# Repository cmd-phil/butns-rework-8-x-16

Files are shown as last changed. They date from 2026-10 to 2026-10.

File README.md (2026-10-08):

# Overview

128 button grid as a rework of jhbruhns 64 clone heavily based on previous work by [hugelton/btns](https://github.com/hugelton/Btns).

overview image

Uses a Rasperry Pi Pico Microcontroller, NeoPixel RGB LEDs (SK6812), cheap buttons and a 3d-printed case and button-overlay.

# Building

It is highly recommended to order the PCB assembled from JLCPCB. That assembly will include everything other than the parts in the BOM.

## BOM

| Part | Quantity | Source | Required | 
|---|---|---|---|
| PCB with components | 1 | JLCPCB, ordered with Gerber and Assembly files from latest release. Gerber: `butns-JLCPCB.zip`, BOM: `butns_bom_jlc.csv`, CPL: `butns_cpl_jlc.csv`. | yes | 
| Raspberry Pi Pico | 1 | Original Raspberry Pi Pico, or [USB-C Variant](https://de.aliexpress.com/item/1005007393927221.html) | yes | |
| M2.5x6 Button Head Screws | 5 | [M2.5x6](https://www.aliexpress.com/item/32810852732.html) | yes | 
| Case | 1 | 3d-printed (FDM). `case.stl` contains the top and bottom half. In the image, it is printed in black PLA, 0.2mm layerheight. | yes | 
| Button Matrix | 1 | 3d-printed (FDM). Print `buttons.stl` with white PLA and 0.12mm layerheight and no infill, 2 wall lines, concentric top infill. These should guide the LEDs light well. Optional: Add `buttons-black-blockers.stl` while importing as a multi-material print and print those in black to block light from neighboring buttons | yes (black blockers optional) | 
| Button TPU Case Inlay | 1 | 3d-printed (FDM). Print with TPU, perhaps in black. Will help against rattling of the buttons in the case. | no | 
| SMD 2.54" Pin Header 1x8 Type A | 1 | [1x8 Type A](https://www.aliexpress.com/item/1005005203849802.html) | no, for tilt | 
| MPU6050 module | 1 | [MPU6050 Module](https://www.aliexpress.com/item/1005006396343851.html) | no, for tilt | 

## Assembly

Flash microcontroller with `firmware.uf2`. Solder MCU and Pin-Header to PCB. Screw everything into the case. Done!

Hint: The cases Top half has one specific orientation where it fits nicely: The top-screw-posts of the top-half with the larger cutoaways go to the side opposite of the USB Connector.

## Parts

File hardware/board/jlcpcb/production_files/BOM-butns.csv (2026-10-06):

Comment | Designator | Footprint | LCSC | Quantity
100nF | C1,C10,C100,C101,C102,C103,C104,C105,C106,C107,C108,C109,C11,C110,C111,C112,C113,C114,C115,C116,C117,C118,C119,C12,C120,C121,C122,C123,C124,C125,C126,C127,C128,C129,C13,C14,C15,C16,C17,C18,C19,C2,C20,C21,C22,C23,C24,C25,C26,C27,C28,C29,C3,C30,C31,C32,C33,C34,C35,C36,C37,C38,C39,C4,C40,C41,C42,C43,C44,C45,C46,C47,C48,C49,C5,C50,C51,C52,C53,C54,C55,C56,C57,C58,C59,C6,C60,C61,C62,C63,C64,C65,C66,C67,C68,C69,C7,C70,C71,C72,C73,C74,C75,C76,C77,C78,C79,C8,C80,C81,C82,C83,C84,C85,C86,C87,C88,C89,C9,C90,C91,C92,C93,C94,C95,C96,C97,C98,C99 | C_0603_1608Metric | C14663 | 129
1N4148WS | D10,D11,D12,D129,D13,D130,D131,D132,D133,D134,D135,D136,D137,D138,D139,D14,D140,D141,D142,D143,D144,D145,D146,D147,D148,D149,D15,D150,D151,D152,D153,D154,D155,D156,D157,D158,D159,D16,D160,D161,D162,D163,D164,D165,D166,D167,D168,D169,D17,D170,D171,D172,D173,D174,D175,D176,D177,D178,D179,D18,D180,D181,D182,D183,D184,D185,D186,D187,D188,D189,D19,D190,D191,D192,D2,D20,D21,D22,D23,D24,D25,D26,D27,D28,D29,D3,D30,D31,D32,D33,D34,D35,D36,D37,D38,D39,D4,D40,D41,D42,D43,D44,D45,D46,D47,D48,D49,D5,D50,D51,D52,D53,D54,D55,D56,D57,D58,D59,D6,D60,D61,D62,D63,D64,D65,D7,D8,D9 | D_SOD-323 | C2128 | 128
SK6812-EC20 | D1,D100,D101,D102,D103,D104,D105,D106,D107,D108,D109,D110,D111,D112,D113,D114,D115,D116,D117,D118,D119,D120,D121,D122,D123,D124,D125,D126,D127,D128,D193,D194,D195,D196,D197,D198,D199,D200,D201,D202,D203,D204,D205,D206,D207,D208,D209,D210,D211,D212,D213,D214,D215,D216,D217,D218,D219,D220,D221,D222,D223,D224,D225,D226,D227,D228,D229,D230,D231,D232,D233,D234,D235,D236,D237,D238,D239,D240,D241,D242,D243,D244,D245,D246,D247,D248,D249,D250,D251,D252,D253,D254,D255,D256,D66,D67,D68,D69,D70,D71,D72,D73,D74,D75,D76,D77,D78,D79,D80,D81,D82,D83,D84,D85,D86,D87,D88,D89,D90,D91,D92,D93,D94,D95,D96,D97,D98,D99 | SK6812-EC20 | C2909058 | 128
SW_Push | SW1,SW10,SW100,SW101,SW102,SW103,SW104,SW105,SW106,SW107,SW108,SW109,SW11,SW110,SW111,SW112,SW113,SW114,SW115,SW116,SW117,SW118,SW119,SW12,SW120,SW121,SW122,SW123,SW124,SW125,SW126,SW127,SW128,SW13,SW14,SW15,SW16,SW17,SW18,SW19,SW2,SW20,SW21,SW22,SW23,SW24,SW25,SW26,SW27,SW28,SW29,SW3,SW30,SW31,SW32,SW33,SW34,SW35,SW36,SW37,SW38,SW39,SW4,SW40,SW41,SW42,SW43,SW44,SW45,SW46,SW47,SW48,SW49,SW5,SW50,SW51,SW52,SW53,SW54,SW55,SW56,SW57,SW58,SW59,SW6,SW60,SW61,SW62,SW63,SW64,SW65,SW66,SW67,SW68,SW69,SW7,SW70,SW71,SW72,SW73,SW74,SW75,SW76,SW77,SW78,SW79,SW8,SW80,SW81,SW82,SW83,SW84,SW85,SW86,SW87,SW88,SW89,SW9,SW90,SW91,SW92,SW93,SW94,SW95,SW96,SW97,SW98,SW99 | SW_Push_1P1T_XKB_TS-1187A | C318884 | 128
74LVC1G17 | U2 | SOT-23-5_HandSoldering | C7836 | 1
Pico | U1 | RPi_Pico_SMD_TH |  | 1

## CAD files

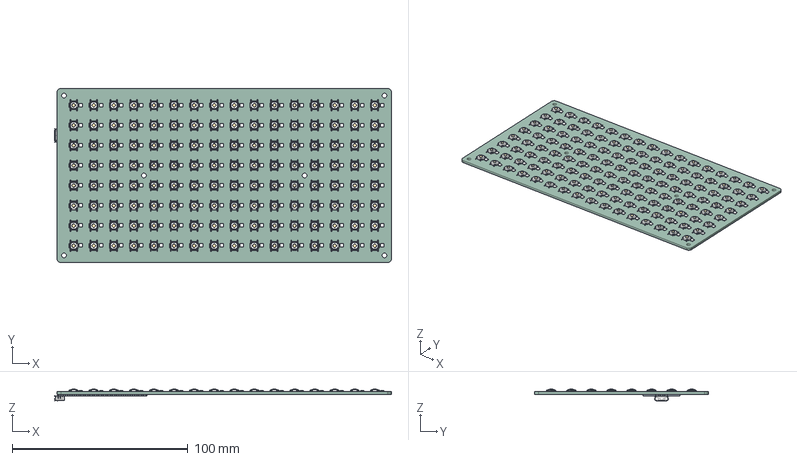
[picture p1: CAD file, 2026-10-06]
hardware/board/butns.step
191.8 x 99.0 x 6.82 mm
SK6812-EC20 x 128
TS-1187A v2 x 128
Raspberry Pi Pico v6
butns_PCB

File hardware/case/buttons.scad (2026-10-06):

include <./roundedcube.scad>

height = 5.3;

s = 8.5;

px = 11.43;
py = 11.4;

cols = 16;
rows = 8;

inlayslack = 1;
rubberslack = .6;

inlayheight = 2.6 - inlayslack;

w = 0.42*3;
h = 0.12*3;

cross = true;

only_blockers = false;

only_inlay = false;

if(!only_blockers && !only_inlay) {
intersection() {
difference() {
union() {
for(x=[0:cols-1]) for(y=[0:rows-1])
translate([x * px, y * py, height / 2]) roundedcube([s, s, height], center = true, radius = 1.5, apply_to = "zmax");

//translate([- s, -s, 0])cube([7 * px + s * 2, 7 * py + s * 2, inlayheight ]);
if (cross) {
for(k=[1-cols/2:rows-1+cols/2])
translate([cols/2 * px, k * py, h/2]) rotate([0, 0, 45]) cube([2*(cols+rows)*px, w, h], center = true);

for(k=[-cols/2:rows-2+cols/2])
translate([cols/2 * px, k * py, h/2]) rotate([0, 0, -45]) cube([2*(cols+rows)*px, w, h], center = true);
} else {
for(x=[0:cols-1]) for(y=[0:rows-1]) {
translate([x * px, y * py - s / 4, h/2]) cube([12, w, h], center=true);
translate([x * px, y * py + s / 4, h/2]) cube([12, w, h], center=true);
translate([x * px - s / 4, y * py, h/2]) cube([w, 12, h], center=true);
translate([x * px + s / 4, y * py, h/2]) cube([w, 12, h], center=true);
}
}

}
translate([3.5 * px, 3.5 * py, 0]) cylinder(h = 20, d = 5.4, center = true);
translate([(cols - 4.5) * px, 3.5 * py, 0]) cylinder(h = 20, d = 5.4, center = true);
translate([-px/2-1, -py/2-1, 0]) cylinder(h = 20, d = 5.8, center = true);
translate([(cols - 0.5) * px+1, (rows - 0.5) * py+1, 0]) cylinder(h = 20, d = 5.8, center = true);
translate([-px/2-1, (rows - 0.5) * py+1, 0]) cylinder(h = 20, d = 5.8, center = true);
translate([(cols - 0.5) * px+1, -py/2-1, 0]) cylinder(h = 20, d = 5.8, center = true);

}
translate([-s/2-1.5, -s/2-1.5, -1]) roundedcube([cols*px-2.9+3, rows*py-2.9+3, 10], radius=1.5, center=false, apply_to = "zmax");


}

for(x=[0:cols-1]) for(y=[0:rows-1])
translate([x * px + s/2, y * py, inlayheight / 2]) cube([3.25, s/3, inlayheight], center = true);

for(y=[0:rows-1])
translate([-1 * px + s - 1, y * py, inlayheight / 2]) cube([2.75, s/4, inlayheight], center = true);
}
if (only_blockers && !only_inlay) {
color("blue")
for(x=[0:cols-1]) for(y=[0:rows-1])
translate([x * px - s/2+.15, y * py, (height - 2) / 2]) cube([.4, s-3, height - 2], center = true);
}

if (!only_blockers && only_inlay) {


color("blue") translate([0, 0, inlayheight]) difference() {
 translate([(cols-1)/2*px, (rows-1)/2*py, (inlayslack - rubberslack) / 2]) cube([(cols-1)*px, (rows-1)*py, inlayslack - rubberslack], center = true);
 
 for(x=[0:cols-1]) for(y=[0:rows-1])
translate([x * px, y * py, height / 2]) roundedcube([s+rubberslack, s + rubberslack, height], center = true, radius = 1.5, apply_to = "zmax");

}
}

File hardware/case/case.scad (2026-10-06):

//-----------------------------------------------------------------------
// Yet Another Parameterized Projectbox generator
//
//  This is a box for <template>
//
//  Version 3.3.0 (2024-11-27)
//
// This design is parameterized based on the size of a PCB.
//
// For many/complex cutoutGrills, you might need to adjust
//  the max number of elements in OpenSCAD:
//
//      Preferences->Advanced->Turn off rendering at 250000 elements
//                                                   ^^^^^^
//
//-----------------------------------------------------------------------



include <./YAPP_Box/YAPPgenerator_v3.scad>

//---------------------------------------------------------
// This design is parameterized based on the size of a PCB.
//---------------------------------------------------------
// Note: length/lengte refers to X axis, 
//       width/breedte refers to Y axis,
//       height/hoogte refers to Z axis

/*
      padding-back|<------pcb length --->|<padding-front
                            RIGHT
        0    X-axis ---> 
        +----------------------------------------+   ---
        |                                        |    ^
        |                                        |   padding-right 
      Y |                                        |    v
      | |    -5,y +----------------------+       |   ---              
 B    a |         | 0,y              x,y |       |     ^              F
 A    x |         |                      |       |     |              R
 C    i |         |                      |       |     | pcb width    O
 K    s |         |                      |       |     |              N
        |         | 0,0              x,0 |       |     v              T
      ^ |    -5,0 +----------------------+       |   ---
      | |                                        |    padding-left
      0 +----------------------------------------+   ---
        0    X-as --->
                          LEFT
*/


//-- which part(s) do you want to print?
printBaseShell        = true;
printLidShell         = true;
printSwitchExtenders  = true;
printDisplayClips     = true;

// ********************************************************************
// The Following will be used as the first element in the pbc array

//Defined here so you can define the "Main" PCB using these if wanted
pcbLength           = 99; // front to back (X axis)
// 16 columns: 99 mm + 8 * 11.43 mm
pcbWidth            = 99 + 8 * 11.43; // side to side (Y axis)
pcbThickness        = 1.6; 
standoffHeight      = 15; //-- How much the PCB needs to be raised from the base to leave room for solderings and whatnot
standoffDiameter    = 6;
standoffPinDiameter = 2.5;
standoffHoleSlack   = 0.4;

myPcb = "../butns.stl";

if ($preview)
{
  translate([pcbLength/2+2.5,pcbWidth/2+2.5,pcbThickness + standoffHeight]) 
  {
    rotate([0,0,90]) color("darkgray") import(myPcb);
  }
}
//===================================================================
// *** PCBs ***
// Printed Circuit Boards
//-------------------------------------------------------------------
//  Default origin =  yappCoordPCB : yappCoordBoxInside[0,0,0]
//
//  Parameters:
//   Required:
//    p(0) = name
//    p(1) = length
//    p(2) = width
//    p(3) = posx
//    p(4) = posy
//    p(5) = Thickness
//    p(6) = standoff_Height
//    p(7) = standoff_Diameter
//    p(8) = standoff_PinDiameter
//   Optional:
//    p(9) = standoff_HoleSlack (default to 0.4)

//The following can be used to get PCB values elsewhere in the script - not in pcb definition. 
//If "PCB Name" is omitted then "Main" is used
//  pcbLength           --> pcbLength("PCB Name")
//  pcbWidth            --> pcbWidth("PCB Name")
//  pcbThickness        --> pcbThickness("PCB Name") 
//  standoffHeight      --> standoffHeight("PCB Name") 
//  standoffDiameter    --> standoffDiameter("PCB Name") 
//  standoffPinDiameter --> standoffPinDiameter("PCB Name") 
//  standoffHoleSlack   --> standoffHoleSlack("PCB Name") 

pcb = 
[
  // Default Main PCB - DO NOT REMOVE the "Main" line.
  ["Main",              pcbLength,pcbWidth,    0,0,    pcbThickness,  standoffHeight, standoffDiameter, standoffPinDiameter, standoffHoleSlack]
];

//-------------------------------------------------------------------                            
//-- padding between pcb and inside wall
paddingFront        = .5;
paddingBack         = .5;
paddingRight        = 1.5;
paddingLeft         = .5;

//-- Edit these parameters for your own box dimensions
wallThickness       = 1.5;
basePlaneThickness  = 2;
lidPlaneThickness   = 2;

//-- Total height of box = lidPlaneThickness 
//                       + lidWallHeight 
//--                     + baseWallHeight 
//                       + basePlaneThickness
//-- space between pcb and lidPlane :=
//--      (bottonWallHeight+lidWallHeight) - (standoffHeight+pcbThickness)
baseWallHeight      = 18;
lidWallHeight       = 2;

//-- e where base and lid off box can overlap
//-- Make sure this isn't less than lidWallHeight
ridgeHeight         = 3;
ridgeSlack          = 0.2;
roundRadius         = 2.0;

// Box Types are 0-4 with 0 as the default
// 0 = All edges rounded with radius (roundRadius) above
// 1 = All edges sqrtuare
// 2 = All edges chamfered by (roundRadius) above 
// 3 = Square top and bottom edges (the ones that touch the build plate) and rounded vertical edges
// 4 = Square top and bottom edges (the ones that touch the build plate) and chamfered vertical edges
// 5 = Chanfered top and bottom edges (the ones that touch the build plate) and rounded vertical edges
boxType             = 3; // Default type 0

// Set the layer height of your printer
printerLayerHeight  = 0.2;


//---------------------------
//--     C O N T R O L     --
//---------------------------
// -- Render --
renderQuality             = 8;          //-> from 1 to 32, Default = 8

// --Preview --
previewQuality            = 5;          //-> from 1 to 32, Default = 5
showSideBySide            = false;       //-> Default = true
onLidGap                  = 0;  // tip don't override to animate the lid opening
colorLid                  = "YellowGreen";   
alphaLid                  = 1;
colorBase                 = "BurlyWood";
alphaBase                 = 1;
hideLidWalls              = false;      //-> Remove the walls from the lid : only if preview and showSideBySide=true 
hideBaseWalls             = false;      //-> Remove the walls from the base : only if preview and showSideBySide=true  
showOrientation           = true;       //-> Show the Front/Back/Left/Right labels : only in preview
showPCB                   = false;      //-> Show the PCB in red : only in preview 
showSwitches              = false;      //-> Show the switches (for pushbuttons) : only in preview 
showButtonsDepressed      = false;      //-> Should the buttons in the Lid On view be in the pressed position
showOriginCoordBox        = false;      //-> Shows red bars representing the origin for yappCoordBox : only in preview 
showOriginCoordBoxInside  = false;      //-> Shows blue bars representing the origin for yappCoordBoxInside : only in preview 
showOriginCoordPCB        = false;      //-> Shows blue bars representing the origin for yappCoordBoxInside : only in preview 
showMarkersPCB            = false;      //-> Shows black bars corners of the PCB : only in preview 
showMarkersCenter         = false;      //-> Shows magenta bars along the centers of all faces  
inspectX                  = 0;          //-> 0=none (>0 from Back)
inspectY                  = 6;          //-> 0=none (>0 from Right)
inspectZ                  = 0;          //-> 0=none (>0 from Bottom)
inspectXfromBack          = true;       //-> View from the inspection cut foreward
inspectYfromLeft          = true;       //-> View from the inspection cut to the right
inspectZfromBottom        = true;       //-> View from the inspection cut up
//---------------------------
//--     C O N T R O L     --
//---------------------------

//-------------------------------------------------------------------
//-------------------------------------------------------------------
// Start of Debugging config (used if not overridden in template)
// ------------------------------------------------------------------
// ------------------------------------------------------------------
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

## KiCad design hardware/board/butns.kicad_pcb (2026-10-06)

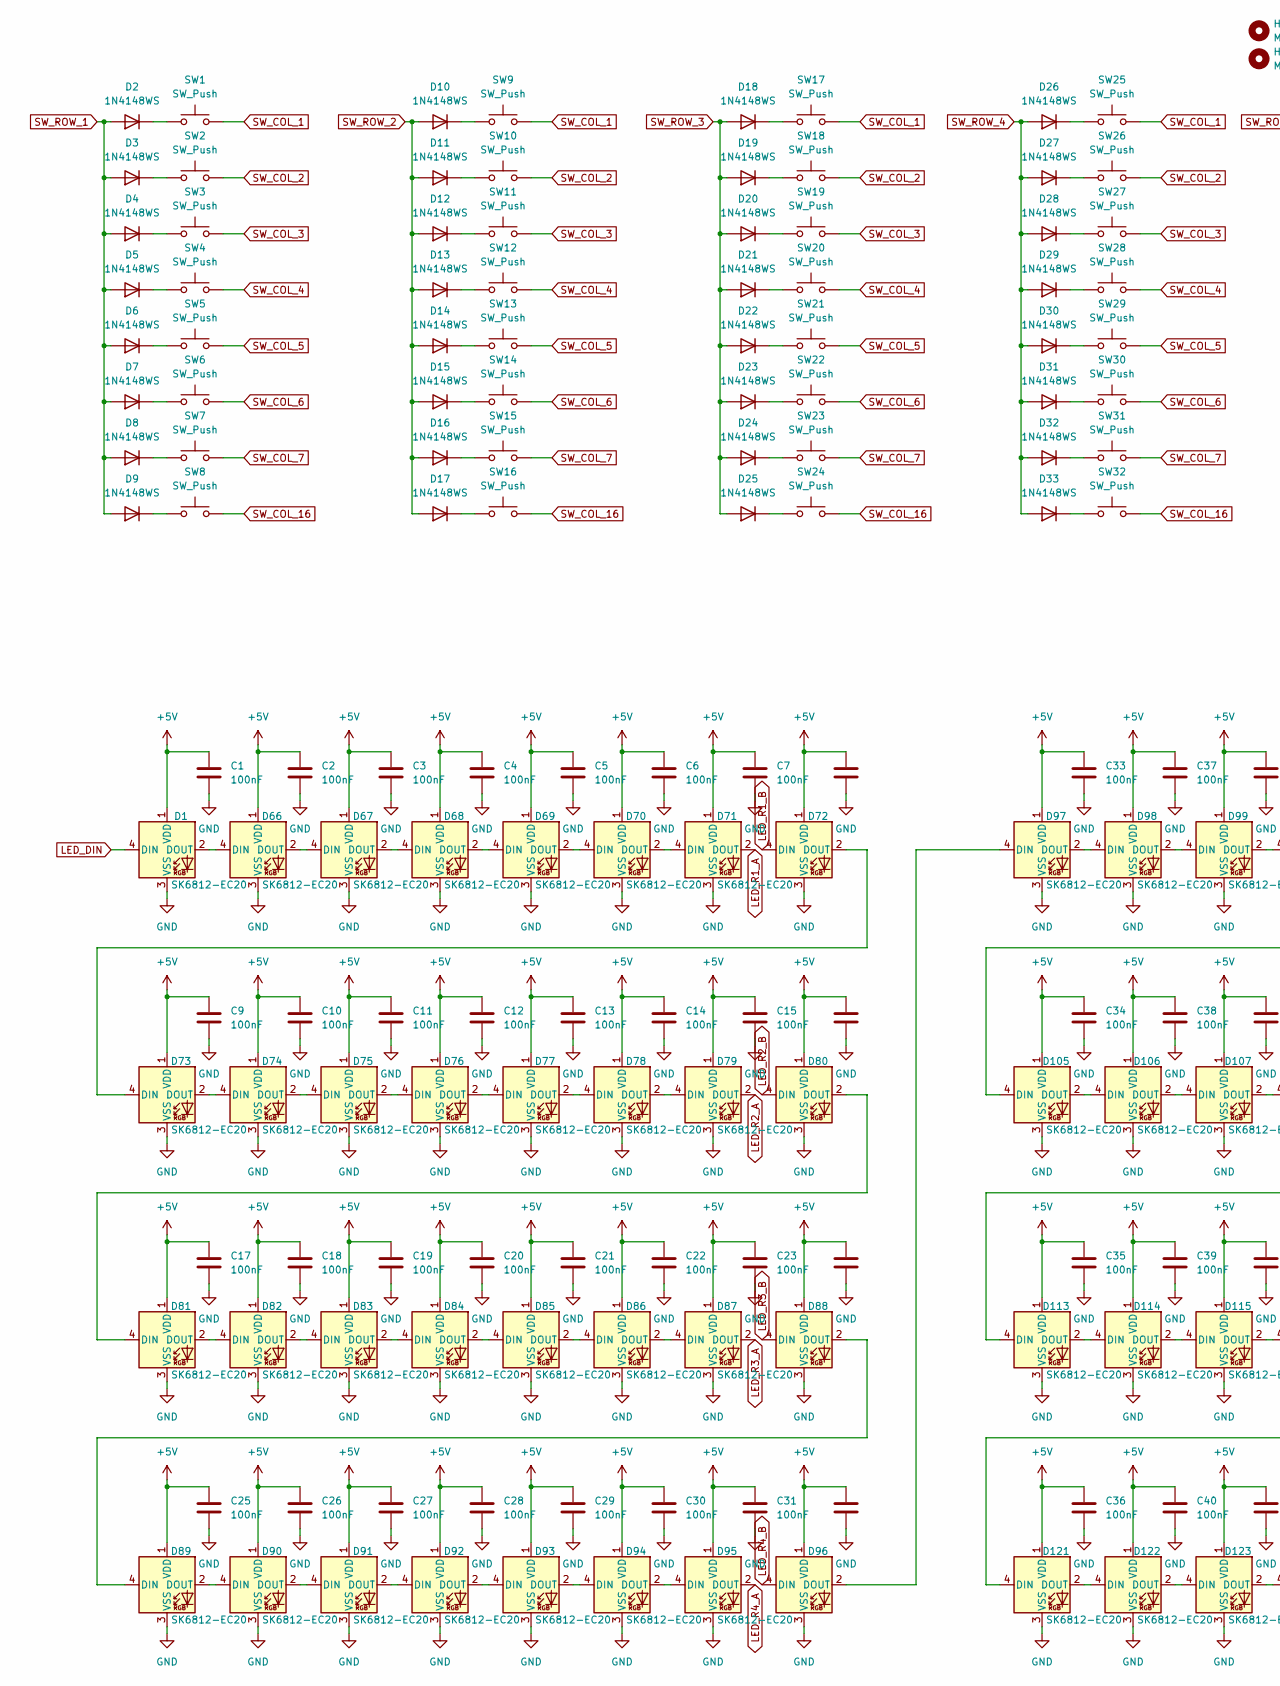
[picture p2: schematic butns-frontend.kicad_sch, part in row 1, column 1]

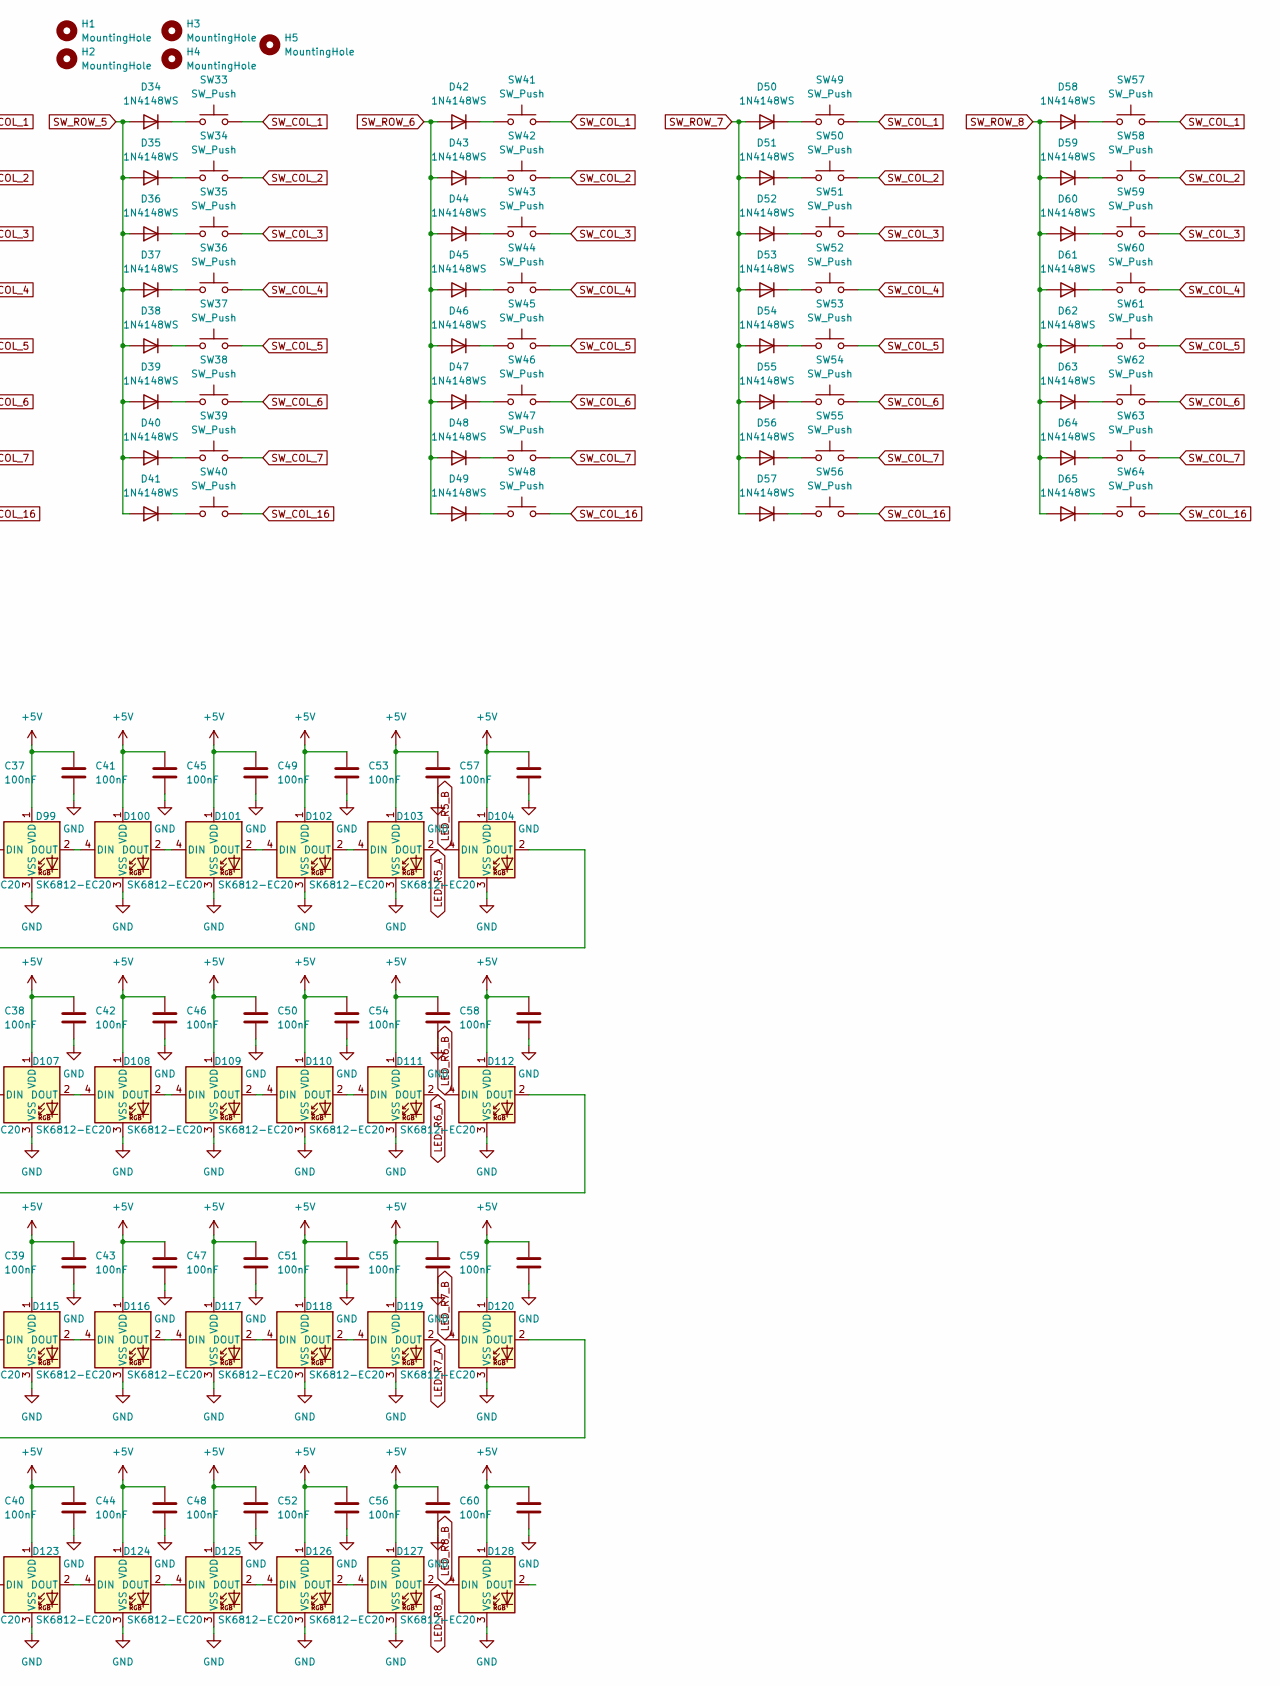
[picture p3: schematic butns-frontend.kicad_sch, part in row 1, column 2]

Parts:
C1, C2, C3, C4, C5, C6, C7, C8, C9, C10, C11, C12, C13, C14, C15, C16, C17, C18, C19, C20, C21, C22, C23, C24, C25, C26, C27, C28, C29, C30, C31, C32, C33, C34, C35, C36, C37, C38, C39, C40, C41, C42, C43, C44, C45, C46, C47, C48, C49, C50, C51, C52, C53, C54, C55, C56, C57, C58, C59, C60, C61, C62, C63, C64: 100nF; C_0603_1608Metric; LCSC C14663
D1, D66, D67, D68, D69, D70, D71, D72, D73, D74, D75, D76, D77, D78, D79, D80, D81, D82, D83, D84, D85, D86, D87, D88, D89, D90, D91, D92, D93, D94, D95, D96, D97, D98, D99, D100, D101, D102, D103, D104, D105, D106, D107, D108, D109, D110, D111, D112, D113, D114, D115, D116, D117, D118, D119, D120, D121, D122, D123, D124, D125, D126, D127, D128: SK6812-EC20; LCSC C2909058
D2, D3, D4, D5, D6, D7, D8, D9, D10, D11, D12, D13, D14, D15, D16, D17, D18, D19, D20, D21, D22, D23, D24, D25, D26, D27, D28, D29, D30, D31, D32, D33, D34, D35, D36, D37, D38, D39, D40, D41, D42, D43, D44, D45, D46, D47, D48, D49, D50, D51, D52, D53, D54, D55, D56, D57, D58, D59, D60, D61, D62, D63, D64, D65: 1N4148WS; D_SOD-323; LCSC C2128
H1, H2, H3, H4, H5: MountingHole; MountingHole_2.7mm_M2.5
SW1, SW2, SW3, SW4, SW5, SW6, SW7, SW8, SW9, SW10, SW11, SW12, SW13, SW14, SW15, SW16, SW17, SW18, SW19, SW20, SW21, SW22, SW23, SW24, SW25, SW26, SW27, SW28, SW29, SW30, SW31, SW32, SW33, SW34, SW35, SW36, SW37, SW38, SW39, SW40, SW41, SW42, SW43, SW44, SW45, SW46, SW47, SW48, SW49, SW50, SW51, SW52, SW53, SW54, SW55, SW56, SW57, SW58, SW59, SW60, SW61, SW62, SW63, SW64: SW_Push; SW_Push_1P1T_XKB_TS-1187A; LCSC C318884

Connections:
+5V: C1.1, C2.1, C3.1, C4.1, C5.1, C6.1, C7.1, C8.1, C9.1, C10.1, C11.1, C12.1, C13.1, C14.1, C15.1, C16.1, C17.1, C18.1, C19.1, C20.1, C21.1, C22.1, C23.1, C24.1, C25.1, C26.1, C27.1, C28.1, C29.1, C30.1, C31.1, C32.1, C33.1, C34.1, C35.1, C36.1, C37.1, C38.1, C39.1, C40.1, C41.1, C42.1, C43.1, C44.1, C45.1, C46.1, C47.1, C48.1, C49.1, C50.1, C51.1, C52.1, C53.1, C54.1, C55.1, C56.1, C57.1, C58.1, C59.1, C60.1, C61.1, C62.1, C63.1, C64.1, D1.1 (VDD), D66.1 (VDD), D67.1 (VDD), D68.1 (VDD), D69.1 (VDD), D70.1 (VDD), D71.1 (VDD), D72.1 (VDD), D73.1 (VDD), D74.1 (VDD), D75.1 (VDD), D76.1 (VDD), D77.1 (VDD), D78.1 (VDD), D79.1 (VDD), D80.1 (VDD), D81.1 (VDD), D82.1 (VDD), D83.1 (VDD), D84.1 (VDD), D85.1 (VDD), D86.1 (VDD), D87.1 (VDD), D88.1 (VDD), D89.1 (VDD), D90.1 (VDD), D91.1 (VDD), D92.1 (VDD), D93.1 (VDD), D94.1 (VDD), D95.1 (VDD), D96.1 (VDD), D97.1 (VDD), D98.1 (VDD), D99.1 (VDD), D100.1 (VDD), D101.1 (VDD), D102.1 (VDD), D103.1 (VDD), D104.1 (VDD), D105.1 (VDD), D106.1 (VDD), D107.1 (VDD), D108.1 (VDD), D109.1 (VDD), D110.1 (VDD), D111.1 (VDD), D112.1 (VDD), D113.1 (VDD), D114.1 (VDD), D115.1 (VDD), D116.1 (VDD), D117.1 (VDD), D118.1 (VDD), D119.1 (VDD), D120.1 (VDD), D121.1 (VDD), D122.1 (VDD), D123.1 (VDD), D124.1 (VDD), D125.1 (VDD), D126.1 (VDD), D127.1 (VDD), D128.1 (VDD); also elsewhere on the board
GND: C1.2, C2.2, C3.2, C4.2, C5.2, C6.2, C7.2, C8.2, C9.2, C10.2, C11.2, C12.2, C13.2, C14.2, C15.2, C16.2, C17.2, C18.2, C19.2, C20.2, C21.2, C22.2, C23.2, C24.2, C25.2, C26.2, C27.2, C28.2, C29.2, C30.2, C31.2, C32.2, C33.2, C34.2, C35.2, C36.2, C37.2, C38.2, C39.2, C40.2, C41.2, C42.2, C43.2, C44.2, C45.2, C46.2, C47.2, C48.2, C49.2, C50.2, C51.2, C52.2, C53.2, C54.2, C55.2, C56.2, C57.2, C58.2, C59.2, C60.2, C61.2, C62.2, C63.2, C64.2, D1.3 (VSS), D66.3 (VSS), D67.3 (VSS), D68.3 (VSS), D69.3 (VSS), D70.3 (VSS), D71.3 (VSS), D72.3 (VSS), D73.3 (VSS), D74.3 (VSS), D75.3 (VSS), D76.3 (VSS), D77.3 (VSS), D78.3 (VSS), D79.3 (VSS), D80.3 (VSS), D81.3 (VSS), D82.3 (VSS), D83.3 (VSS), D84.3 (VSS), D85.3 (VSS), D86.3 (VSS), D87.3 (VSS), D88.3 (VSS), D89.3 (VSS), D90.3 (VSS), D91.3 (VSS), D92.3 (VSS), D93.3 (VSS), D94.3 (VSS), D95.3 (VSS), D96.3 (VSS), D97.3 (VSS), D98.3 (VSS), D99.3 (VSS), D100.3 (VSS), D101.3 (VSS), D102.3 (VSS), D103.3 (VSS), D104.3 (VSS), D105.3 (VSS), D106.3 (VSS), D107.3 (VSS), D108.3 (VSS), D109.3 (VSS), D110.3 (VSS), D111.3 (VSS), D112.3 (VSS), D113.3 (VSS), D114.3 (VSS), D115.3 (VSS), D116.3 (VSS), D117.3 (VSS), D118.3 (VSS), D119.3 (VSS), D120.3 (VSS), D121.3 (VSS), D122.3 (VSS), D123.3 (VSS), D124.3 (VSS), D125.3 (VSS), D126.3 (VSS), D127.3 (VSS), D128.3 (VSS); also elsewhere on the board
LED_DIN: D1.4 (DIN); also elsewhere on the board
LED_R1_A: D71.2 (DOUT); also elsewhere on the board
LED_R1_B: D72.4 (DIN); also elsewhere on the board
LED_R2_A: D79.2 (DOUT); also elsewhere on the board
LED_R2_B: D80.4 (DIN); also elsewhere on the board
LED_R3_A: D87.2 (DOUT); also elsewhere on the board
LED_R3_B: D88.4 (DIN); also elsewhere on the board
LED_R4_A: D95.2 (DOUT); also elsewhere on the board
LED_R4_B: D96.4 (DIN); also elsewhere on the board
LED_R5_A: D103.2 (DOUT); also elsewhere on the board
LED_R5_B: D104.4 (DIN); also elsewhere on the board
LED_R6_A: D111.2 (DOUT); also elsewhere on the board
LED_R6_B: D112.4 (DIN); also elsewhere on the board
LED_R7_A: D119.2 (DOUT); also elsewhere on the board
LED_R7_B: D120.4 (DIN); also elsewhere on the board
LED_R8_A: D127.2 (DOUT); also elsewhere on the board
LED_R8_B: D128.4 (DIN); also elsewhere on the board
unnamed: D1.2 (DOUT), D66.4 (DIN)
unnamed: D2.1 (K), SW1.1
unnamed: D3.1 (K), SW2.1
unnamed: D4.1 (K), SW3.1
unnamed: D5.1 (K), SW4.1
unnamed: D6.1 (K), SW5.1
unnamed: D7.1 (K), SW6.1
unnamed: D8.1 (K), SW7.1
unnamed: D9.1 (K), SW8.1
unnamed: D10.1 (K), SW9.1
unnamed: D11.1 (K), SW10.1
unnamed: D12.1 (K), SW11.1
unnamed: D13.1 (K), SW12.1
unnamed: D14.1 (K), SW13.1
unnamed: D15.1 (K), SW14.1
unnamed: D16.1 (K), SW15.1
unnamed: D17.1 (K), SW16.1
unnamed: D18.1 (K), SW17.1
unnamed: D19.1 (K), SW18.1
unnamed: D20.1 (K), SW19.1
unnamed: D21.1 (K), SW20.1
unnamed: D22.1 (K), SW21.1
unnamed: D23.1 (K), SW22.1
unnamed: D24.1 (K), SW23.1
unnamed: D25.1 (K), SW24.1
unnamed: D26.1 (K), SW25.1
unnamed: D27.1 (K), SW26.1
unnamed: D28.1 (K), SW27.1
unnamed: D29.1 (K), SW28.1
unnamed: D30.1 (K), SW29.1
unnamed: D31.1 (K), SW30.1
unnamed: D32.1 (K), SW31.1
unnamed: D33.1 (K), SW32.1
unnamed: D34.1 (K), SW33.1
unnamed: D35.1 (K), SW34.1
unnamed: D36.1 (K), SW35.1
unnamed: D37.1 (K), SW36.1
unnamed: D38.1 (K), SW37.1
unnamed: D39.1 (K), SW38.1
unnamed: D40.1 (K), SW39.1
unnamed: D41.1 (K), SW40.1
unnamed: D42.1 (K), SW41.1
unnamed: D43.1 (K), SW42.1
unnamed: D44.1 (K), SW43.1
unnamed: D45.1 (K), SW44.1
unnamed: D46.1 (K), SW45.1
unnamed: D47.1 (K), SW46.1
unnamed: D48.1 (K), SW47.1
unnamed: D49.1 (K), SW48.1
unnamed: D50.1 (K), SW49.1
unnamed: D51.1 (K), SW50.1
unnamed: D52.1 (K), SW51.1
unnamed: D53.1 (K), SW52.1
unnamed: D54.1 (K), SW53.1
unnamed: D55.1 (K), SW54.1
unnamed: D56.1 (K), SW55.1
unnamed: D57.1 (K), SW56.1
unnamed: D58.1 (K), SW57.1
unnamed: D59.1 (K), SW58.1
unnamed: D60.1 (K), SW59.1
unnamed: D61.1 (K), SW60.1
unnamed: D62.1 (K), SW61.1
unnamed: D63.1 (K), SW62.1
unnamed: D64.1 (K), SW63.1
unnamed: D65.1 (K), SW64.1
unnamed: D66.2 (DOUT), D67.4 (DIN)
unnamed: D67.2 (DOUT), D68.4 (DIN)
unnamed: D68.2 (DOUT), D69.4 (DIN)
unnamed: D69.2 (DOUT), D70.4 (DIN)
unnamed: D70.2 (DOUT), D71.4 (DIN)
unnamed: D72.2 (DOUT), D73.4 (DIN)
unnamed: D73.2 (DOUT), D74.4 (DIN)
unnamed: D74.2 (DOUT), D75.4 (DIN)
unnamed: D75.2 (DOUT), D76.4 (DIN)
unnamed: D76.2 (DOUT), D77.4 (DIN)
unnamed: D77.2 (DOUT), D78.4 (DIN)
unnamed: D78.2 (DOUT), D79.4 (DIN)
unnamed: D80.2 (DOUT), D81.4 (DIN)
unnamed: D81.2 (DOUT), D82.4 (DIN)
unnamed: D82.2 (DOUT), D83.4 (DIN)
unnamed: D83.2 (DOUT), D84.4 (DIN)
unnamed: D84.2 (DOUT), D85.4 (DIN)
unnamed: D85.2 (DOUT), D86.4 (DIN)
unnamed: D86.2 (DOUT), D87.4 (DIN)
unnamed: D88.2 (DOUT), D89.4 (DIN)
unnamed: D89.2 (DOUT), D90.4 (DIN)
unnamed: D90.2 (DOUT), D91.4 (DIN)
unnamed: D91.2 (DOUT), D92.4 (DIN)
unnamed: D92.2 (DOUT), D93.4 (DIN)
unnamed: D93.2 (DOUT), D94.4 (DIN)
unnamed: D94.2 (DOUT), D95.4 (DIN)
unnamed: D96.2 (DOUT), D97.4 (DIN)
unnamed: D97.2 (DOUT), D98.4 (DIN)
unnamed: D98.2 (DOUT), D99.4 (DIN)
unnamed: D99.2 (DOUT), D100.4 (DIN)
unnamed: D100.2 (DOUT), D101.4 (DIN)
unnamed: D101.2 (DOUT), D102.4 (DIN)
unnamed: D102.2 (DOUT), D103.4 (DIN)
unnamed: D104.2 (DOUT), D105.4 (DIN)
unnamed: D105.2 (DOUT), D106.4 (DIN)
unnamed: D106.2 (DOUT), D107.4 (DIN)
unnamed: D107.2 (DOUT), D108.4 (DIN)
unnamed: D108.2 (DOUT), D109.4 (DIN)
unnamed: D109.2 (DOUT), D110.4 (DIN)
unnamed: D110.2 (DOUT), D111.4 (DIN)
unnamed: D112.2 (DOUT), D113.4 (DIN)
unnamed: D113.2 (DOUT), D114.4 (DIN)
unnamed: D114.2 (DOUT), D115.4 (DIN)
unnamed: D115.2 (DOUT), D116.4 (DIN)
unnamed: D116.2 (DOUT), D117.4 (DIN)
unnamed: D117.2 (DOUT), D118.4 (DIN)
unnamed: D118.2 (DOUT), D119.4 (DIN)
unnamed: D120.2 (DOUT), D121.4 (DIN)
unnamed: D121.2 (DOUT), D122.4 (DIN)
unnamed: D122.2 (DOUT), D123.4 (DIN)
unnamed: D123.2 (DOUT), D124.4 (DIN)
unnamed: D124.2 (DOUT), D125.4 (DIN)
unnamed: D125.2 (DOUT), D126.4 (DIN)
unnamed: D126.2 (DOUT), D127.4 (DIN)
SW_COL_1: SW1.2, SW9.2, SW17.2, SW25.2, SW33.2, SW41.2, SW49.2, SW57.2; also elsewhere on the board
SW_COL_2: SW2.2, SW10.2, SW18.2, SW26.2, SW34.2, SW42.2, SW50.2, SW58.2; also elsewhere on the board
SW_COL_3: SW3.2, SW11.2, SW19.2, SW27.2, SW35.2, SW43.2, SW51.2, SW59.2; also elsewhere on the board
SW_COL_4: SW4.2, SW12.2, SW20.2, SW28.2, SW36.2, SW44.2, SW52.2, SW60.2; also elsewhere on the board
SW_COL_5: SW5.2, SW13.2, SW21.2, SW29.2, SW37.2, SW45.2, SW53.2, SW61.2; also elsewhere on the board
SW_COL_6: SW6.2, SW14.2, SW22.2, SW30.2, SW38.2, SW46.2, SW54.2, SW62.2; also elsewhere on the board
SW_COL_7: SW7.2, SW15.2, SW23.2, SW31.2, SW39.2, SW47.2, SW55.2, SW63.2; also elsewhere on the board
SW_COL_16: SW8.2, SW16.2, SW24.2, SW32.2, SW40.2, SW48.2, SW56.2, SW64.2; also elsewhere on the board
SW_ROW_1: D2.2 (A), D3.2 (A), D4.2 (A), D5.2 (A), D6.2 (A), D7.2 (A), D8.2 (A), D9.2 (A); also elsewhere on the board
SW_ROW_2: D10.2 (A), D11.2 (A), D12.2 (A), D13.2 (A), D14.2 (A), D15.2 (A), D16.2 (A), D17.2 (A); also elsewhere on the board
SW_ROW_3: D18.2 (A), D19.2 (A), D20.2 (A), D21.2 (A), D22.2 (A), D23.2 (A), D24.2 (A), D25.2 (A); also elsewhere on the board
SW_ROW_4: D26.2 (A), D27.2 (A), D28.2 (A), D29.2 (A), D30.2 (A), D31.2 (A), D32.2 (A), D33.2 (A); also elsewhere on the board
SW_ROW_5: D34.2 (A), D35.2 (A), D36.2 (A), D37.2 (A), D38.2 (A), D39.2 (A), D40.2 (A), D41.2 (A); also elsewhere on the board
SW_ROW_6: D42.2 (A), D43.2 (A), D44.2 (A), D45.2 (A), D46.2 (A), D47.2 (A), D48.2 (A), D49.2 (A); also elsewhere on the board
SW_ROW_7: D50.2 (A), D51.2 (A), D52.2 (A), D53.2 (A), D54.2 (A), D55.2 (A), D56.2 (A), D57.2 (A); also elsewhere on the board
SW_ROW_8: D58.2 (A), D59.2 (A), D60.2 (A), D61.2 (A), D62.2 (A), D63.2 (A), D64.2 (A), D65.2 (A); also elsewhere on the board

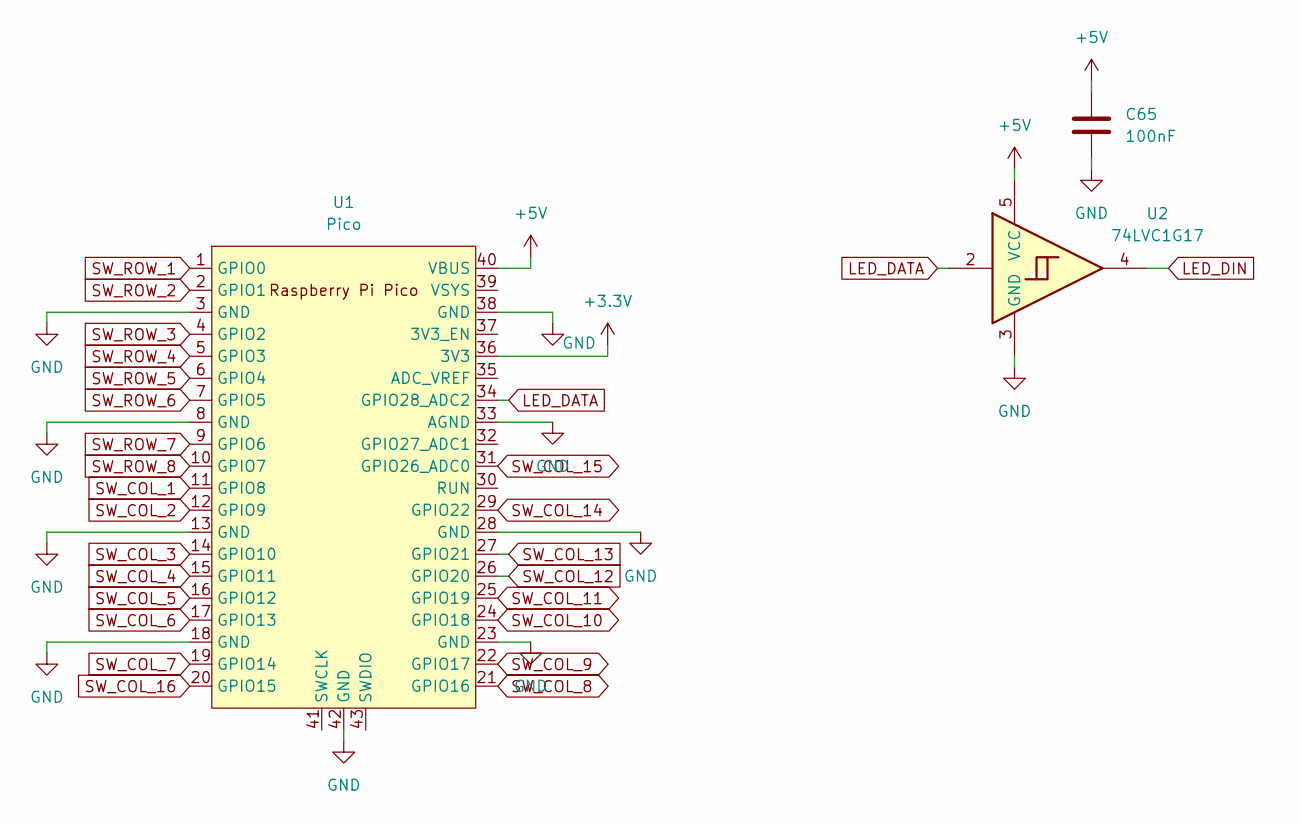
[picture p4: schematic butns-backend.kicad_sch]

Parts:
C65: 100nF; C_0603_1608Metric
U1: Pico; RPi_Pico_SMD_TH
U2: 74LVC1G17; SOT-23-5_HandSoldering

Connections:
+3.3V: U1.36 (3V3)
+5V: C65.1, U1.40 (VBUS), U2.5 (VCC); also elsewhere on the board
GND: C65.2, U1.3 (GND), U1.8 (GND), U1.13 (GND), U1.18 (GND), U1.23 (GND), U1.28 (GND), U1.33 (AGND), U1.38 (GND), U1.42 (GND), U2.3 (GND); also elsewhere on the board
LED_DATA: U1.34 (GPIO28_ADC2), U2.2
LED_DIN: U2.4; also elsewhere on the board
SW_COL_1: U1.11 (GPIO8); also elsewhere on the board
SW_COL_2: U1.12 (GPIO9); also elsewhere on the board
SW_COL_3: U1.14 (GPIO10); also elsewhere on the board
SW_COL_4: U1.15 (GPIO11); also elsewhere on the board
SW_COL_5: U1.16 (GPIO12); also elsewhere on the board
SW_COL_6: U1.17 (GPIO13); also elsewhere on the board
SW_COL_7: U1.19 (GPIO14); also elsewhere on the board
SW_COL_8: U1.21 (GPIO16); also elsewhere on the board
SW_COL_9: U1.22 (GPIO17); also elsewhere on the board
SW_COL_10: U1.24 (GPIO18); also elsewhere on the board
SW_COL_11: U1.25 (GPIO19); also elsewhere on the board
SW_COL_12: U1.26 (GPIO20); also elsewhere on the board
SW_COL_13: U1.27 (GPIO21); also elsewhere on the board
SW_COL_14: U1.29 (GPIO22); also elsewhere on the board
SW_COL_15: U1.31 (GPIO26_ADC0); also elsewhere on the board
SW_COL_16: U1.20 (GPIO15); also elsewhere on the board
SW_ROW_1: U1.1 (GPIO0); also elsewhere on the board
SW_ROW_2: U1.2 (GPIO1); also elsewhere on the board
SW_ROW_3: U1.4 (GPIO2); also elsewhere on the board
SW_ROW_4: U1.5 (GPIO3); also elsewhere on the board
SW_ROW_5: U1.6 (GPIO4); also elsewhere on the board
SW_ROW_6: U1.7 (GPIO5); also elsewhere on the board
SW_ROW_7: U1.9 (GPIO6); also elsewhere on the board
SW_ROW_8: U1.10 (GPIO7); also elsewhere on the board

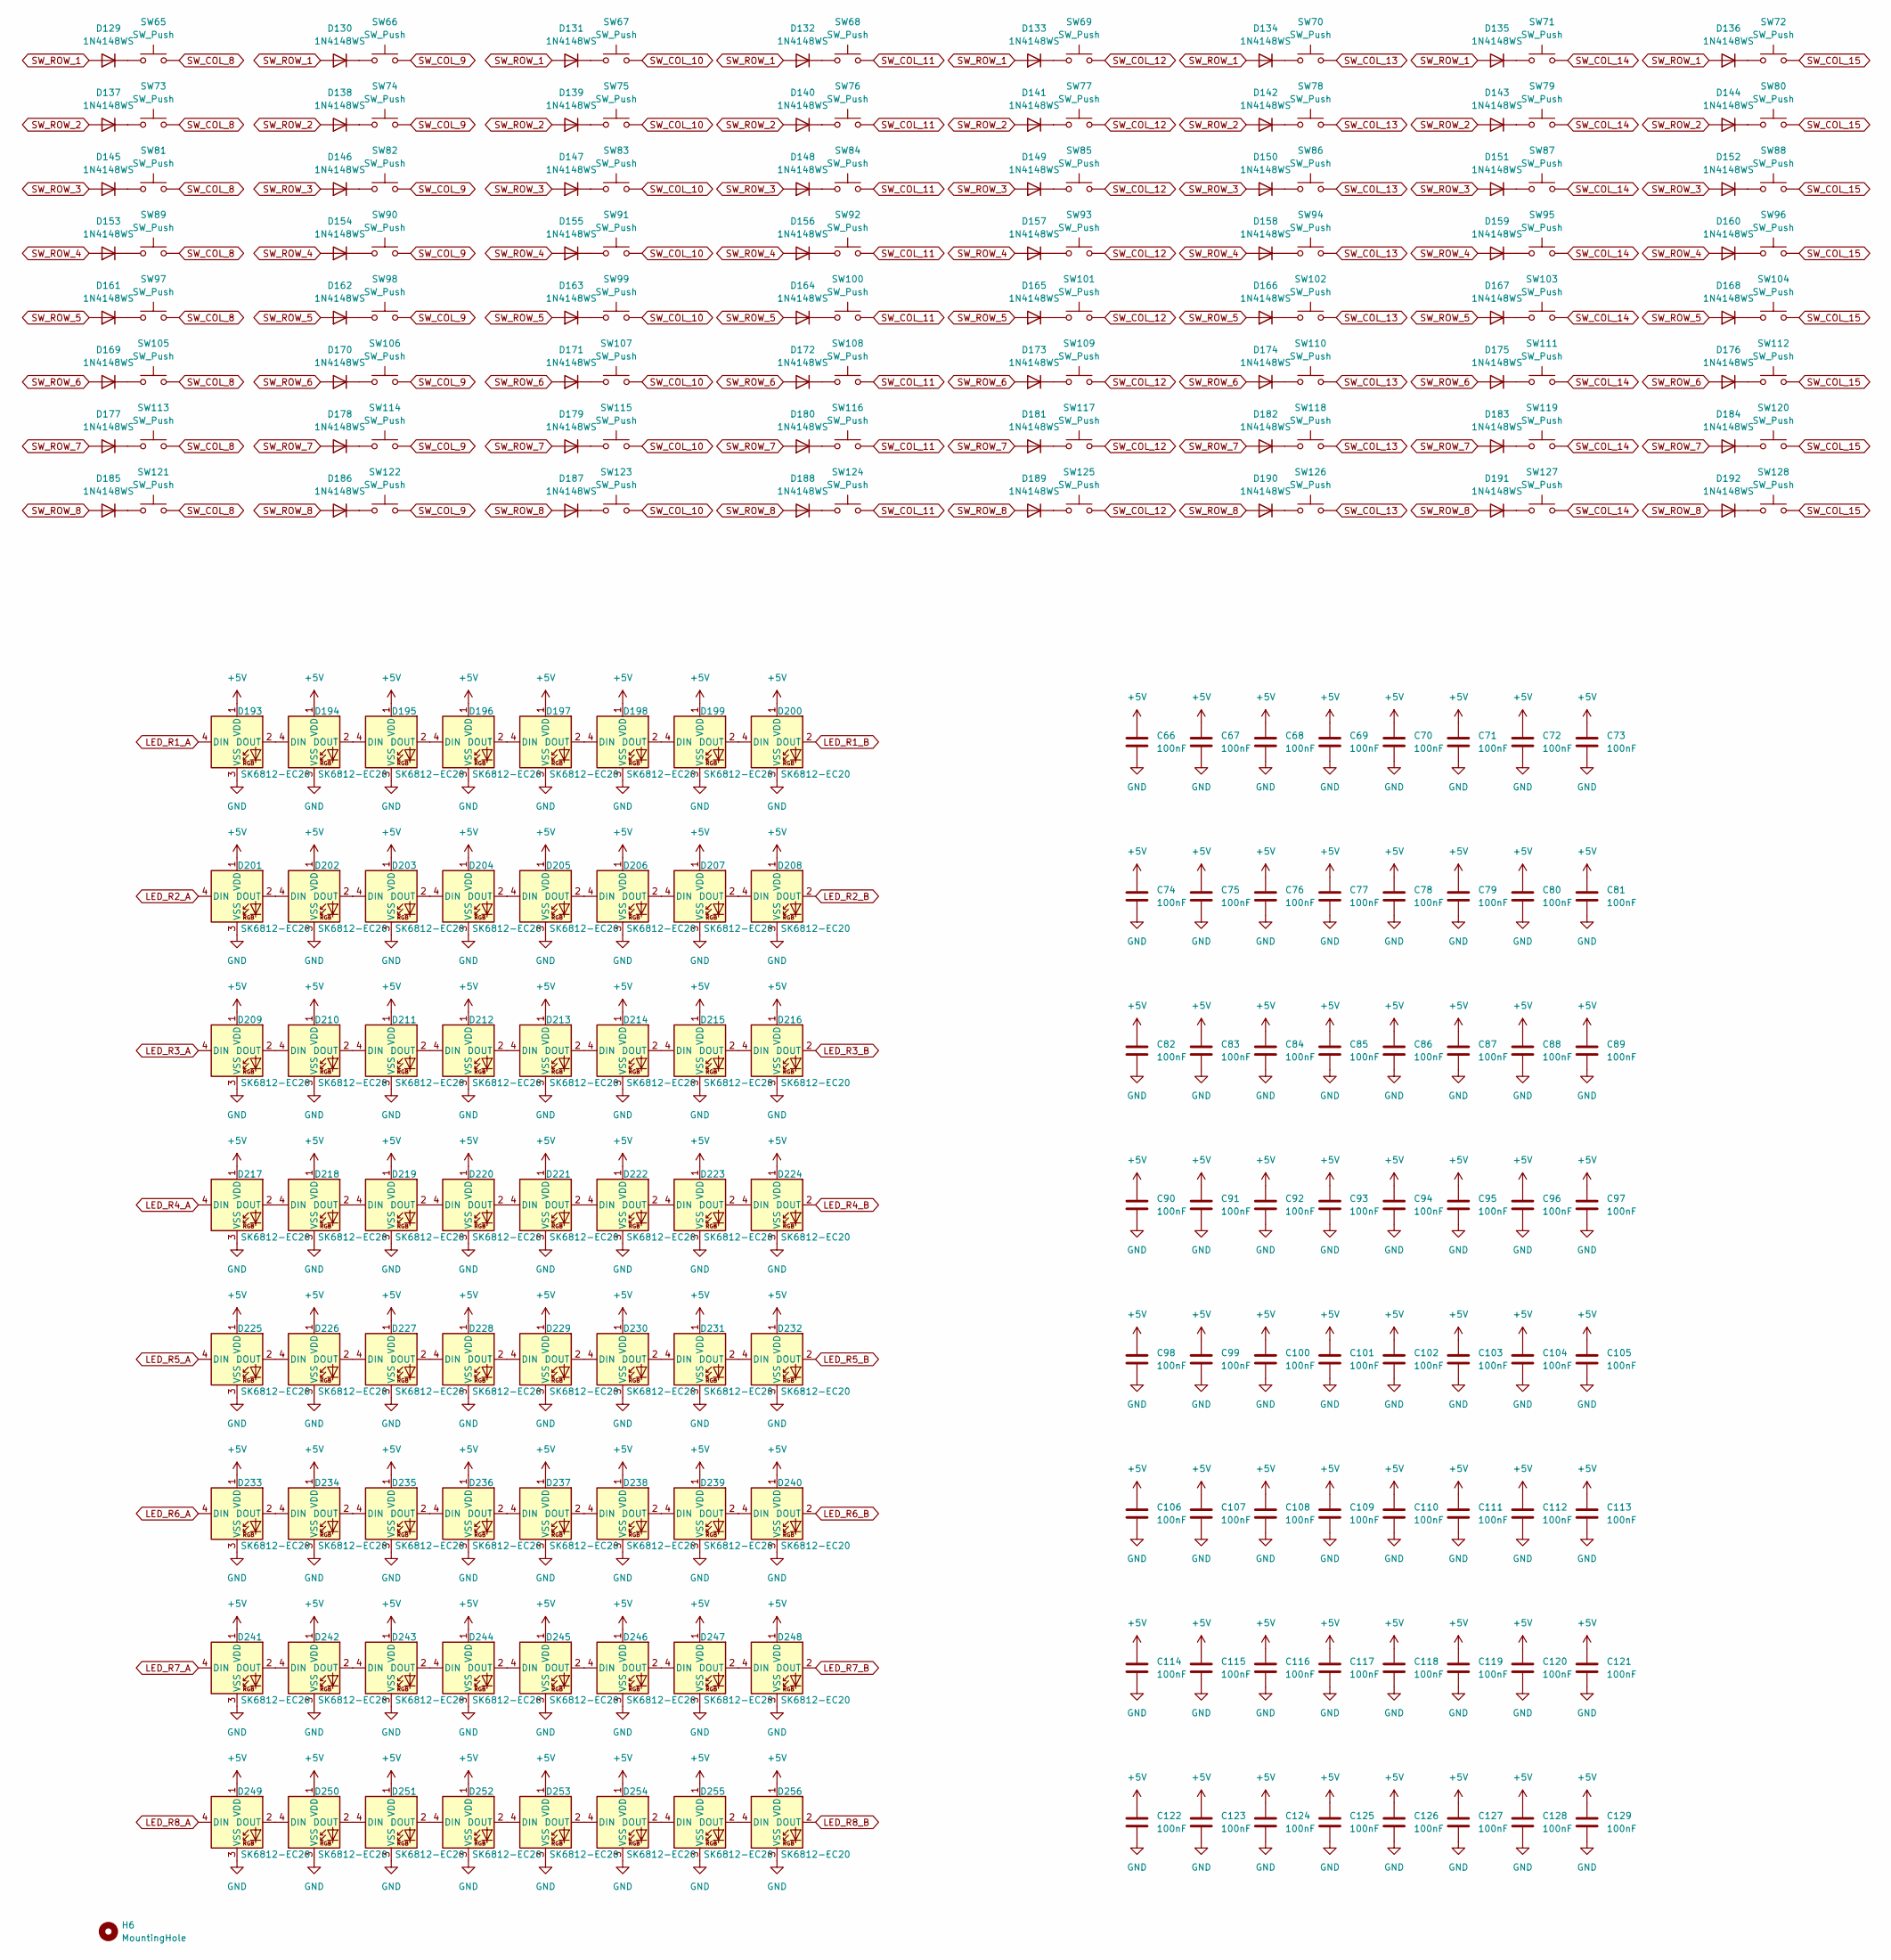
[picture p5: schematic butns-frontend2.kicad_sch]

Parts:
C66, C67, C68, C69, C70, C71, C72, C73, C74, C75, C76, C77, C78, C79, C80, C81, C82, C83, C84, C85, C86, C87, C88, C89, C90, C91, C92, C93, C94, C95, C96, C97, C98, C99, C100, C101, C102, C103, C104, C105, C106, C107, C108, C109, C110, C111, C112, C113, C114, C115, C116, C117, C118, C119, C120, C121, C122, C123, C124, C125, C126, C127, C128, C129: 100nF; C_0603_1608Metric; LCSC C14663
D129, D130, D131, D132, D133, D134, D135, D136, D137, D138, D139, D140, D141, D142, D143, D144, D145, D146, D147, D148, D149, D150, D151, D152, D153, D154, D155, D156, D157, D158, D159, D160, D161, D162, D163, D164, D165, D166, D167, D168, D169, D170, D171, D172, D173, D174, D175, D176, D177, D178, D179, D180, D181, D182, D183, D184, D185, D186, D187, D188, D189, D190, D191, D192: 1N4148WS; D_SOD-323; LCSC C2128
D193, D194, D195, D196, D197, D198, D199, D200, D201, D202, D203, D204, D205, D206, D207, D208, D209, D210, D211, D212, D213, D214, D215, D216, D217, D218, D219, D220, D221, D222, D223, D224, D225, D226, D227, D228, D229, D230, D231, D232, D233, D234, D235, D236, D237, D238, D239, D240, D241, D242, D243, D244, D245, D246, D247, D248, D249, D250, D251, D252, D253, D254, D255, D256: SK6812-EC20; LCSC C2909058
H6: MountingHole; MountingHole_2.7mm_M2.5
SW65, SW66, SW67, SW68, SW69, SW70, SW71, SW72, SW73, SW74, SW75, SW76, SW77, SW78, SW79, SW80, SW81, SW82, SW83, SW84, SW85, SW86, SW87, SW88, SW89, SW90, SW91, SW92, SW93, SW94, SW95, SW96, SW97, SW98, SW99, SW100, SW101, SW102, SW103, SW104, SW105, SW106, SW107, SW108, SW109, SW110, SW111, SW112, SW113, SW114, SW115, SW116, SW117, SW118, SW119, SW120, SW121, SW122, SW123, SW124, SW125, SW126, SW127, SW128: SW_Push; SW_Push_1P1T_XKB_TS-1187A; LCSC C318884

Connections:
+5V: C66.1, C67.1, C68.1, C69.1, C70.1, C71.1, C72.1, C73.1, C74.1, C75.1, C76.1, C77.1, C78.1, C79.1, C80.1, C81.1, C82.1, C83.1, C84.1, C85.1, C86.1, C87.1, C88.1, C89.1, C90.1, C91.1, C92.1, C93.1, C94.1, C95.1, C96.1, C97.1, C98.1, C99.1, C100.1, C101.1, C102.1, C103.1, C104.1, C105.1, C106.1, C107.1, C108.1, C109.1, C110.1, C111.1, C112.1, C113.1, C114.1, C115.1, C116.1, C117.1, C118.1, C119.1, C120.1, C121.1, C122.1, C123.1, C124.1, C125.1, C126.1, C127.1, C128.1, C129.1, D193.1 (VDD), D194.1 (VDD), D195.1 (VDD), D196.1 (VDD), D197.1 (VDD), D198.1 (VDD), D199.1 (VDD), D200.1 (VDD), D201.1 (VDD), D202.1 (VDD), D203.1 (VDD), D204.1 (VDD), D205.1 (VDD), D206.1 (VDD), D207.1 (VDD), D208.1 (VDD), D209.1 (VDD), D210.1 (VDD), D211.1 (VDD), D212.1 (VDD), D213.1 (VDD), D214.1 (VDD), D215.1 (VDD), D216.1 (VDD), D217.1 (VDD), D218.1 (VDD), D219.1 (VDD), D220.1 (VDD), D221.1 (VDD), D222.1 (VDD), D223.1 (VDD), D224.1 (VDD), D225.1 (VDD), D226.1 (VDD), D227.1 (VDD), D228.1 (VDD), D229.1 (VDD), D230.1 (VDD), D231.1 (VDD), D232.1 (VDD), D233.1 (VDD), D234.1 (VDD), D235.1 (VDD), D236.1 (VDD), D237.1 (VDD), D238.1 (VDD), D239.1 (VDD), D240.1 (VDD), D241.1 (VDD), D242.1 (VDD), D243.1 (VDD), D244.1 (VDD), D245.1 (VDD), D246.1 (VDD), D247.1 (VDD), D248.1 (VDD), D249.1 (VDD), D250.1 (VDD), D251.1 (VDD), D252.1 (VDD), D253.1 (VDD), D254.1 (VDD), D255.1 (VDD), D256.1 (VDD); also elsewhere on the board
GND: C66.2, C67.2, C68.2, C69.2, C70.2, C71.2, C72.2, C73.2, C74.2, C75.2, C76.2, C77.2, C78.2, C79.2, C80.2, C81.2, C82.2, C83.2, C84.2, C85.2, C86.2, C87.2, C88.2, C89.2, C90.2, C91.2, C92.2, C93.2, C94.2, C95.2, C96.2, C97.2, C98.2, C99.2, C100.2, C101.2, C102.2, C103.2, C104.2, C105.2, C106.2, C107.2, C108.2, C109.2, C110.2, C111.2, C112.2, C113.2, C114.2, C115.2, C116.2, C117.2, C118.2, C119.2, C120.2, C121.2, C122.2, C123.2, C124.2, C125.2, C126.2, C127.2, C128.2, C129.2, D193.3 (VSS), D194.3 (VSS), D195.3 (VSS), D196.3 (VSS), D197.3 (VSS), D198.3 (VSS), D199.3 (VSS), D200.3 (VSS), D201.3 (VSS), D202.3 (VSS), D203.3 (VSS), D204.3 (VSS), D205.3 (VSS), D206.3 (VSS), D207.3 (VSS), D208.3 (VSS), D209.3 (VSS), D210.3 (VSS), D211.3 (VSS), D212.3 (VSS), D213.3 (VSS), D214.3 (VSS), D215.3 (VSS), D216.3 (VSS), D217.3 (VSS), D218.3 (VSS), D219.3 (VSS), D220.3 (VSS), D221.3 (VSS), D222.3 (VSS), D223.3 (VSS), D224.3 (VSS), D225.3 (VSS), D226.3 (VSS), D227.3 (VSS), D228.3 (VSS), D229.3 (VSS), D230.3 (VSS), D231.3 (VSS), D232.3 (VSS), D233.3 (VSS), D234.3 (VSS), D235.3 (VSS), D236.3 (VSS), D237.3 (VSS), D238.3 (VSS), D239.3 (VSS), D240.3 (VSS), D241.3 (VSS), D242.3 (VSS), D243.3 (VSS), D244.3 (VSS), D245.3 (VSS), D246.3 (VSS), D247.3 (VSS), D248.3 (VSS), D249.3 (VSS), D250.3 (VSS), D251.3 (VSS), D252.3 (VSS), D253.3 (VSS), D254.3 (VSS), D255.3 (VSS), D256.3 (VSS); also elsewhere on the board
LED_R1_A: D193.4 (DIN); also elsewhere on the board
LED_R1_B: D200.2 (DOUT); also elsewhere on the board
LED_R2_A: D201.4 (DIN); also elsewhere on the board
LED_R2_B: D208.2 (DOUT); also elsewhere on the board
LED_R3_A: D209.4 (DIN); also elsewhere on the board
LED_R3_B: D216.2 (DOUT); also elsewhere on the board
LED_R4_A: D217.4 (DIN); also elsewhere on the board
LED_R4_B: D224.2 (DOUT); also elsewhere on the board
LED_R5_A: D225.4 (DIN); also elsewhere on the board
LED_R5_B: D232.2 (DOUT); also elsewhere on the board
LED_R6_A: D233.4 (DIN); also elsewhere on the board
LED_R6_B: D240.2 (DOUT); also elsewhere on the board
LED_R7_A: D241.4 (DIN); also elsewhere on the board
LED_R7_B: D248.2 (DOUT); also elsewhere on the board
LED_R8_A: D249.4 (DIN); also elsewhere on the board
LED_R8_B: D256.2 (DOUT); also elsewhere on the board
unnamed: D129.1 (K), SW65.1
unnamed: D130.1 (K), SW66.1
unnamed: D131.1 (K), SW67.1
unnamed: D132.1 (K), SW68.1
unnamed: D133.1 (K), SW69.1
unnamed: D134.1 (K), SW70.1
unnamed: D135.1 (K), SW71.1
unnamed: D136.1 (K), SW72.1
unnamed: D137.1 (K), SW73.1
unnamed: D138.1 (K), SW74.1
unnamed: D139.1 (K), SW75.1
unnamed: D140.1 (K), SW76.1
unnamed: D141.1 (K), SW77.1
unnamed: D142.1 (K), SW78.1
unnamed: D143.1 (K), SW79.1
unnamed: D144.1 (K), SW80.1
unnamed: D145.1 (K), SW81.1
unnamed: D146.1 (K), SW82.1
unnamed: D147.1 (K), SW83.1
unnamed: D148.1 (K), SW84.1
unnamed: D149.1 (K), SW85.1
unnamed: D150.1 (K), SW86.1
unnamed: D151.1 (K), SW87.1
unnamed: D152.1 (K), SW88.1
unnamed: D153.1 (K), SW89.1
unnamed: D154.1 (K), SW90.1
unnamed: D155.1 (K), SW91.1
unnamed: D156.1 (K), SW92.1
unnamed: D157.1 (K), SW93.1
unnamed: D158.1 (K), SW94.1
unnamed: D159.1 (K), SW95.1
unnamed: D160.1 (K), SW96.1
unnamed: D161.1 (K), SW97.1
unnamed: D162.1 (K), SW98.1
unnamed: D163.1 (K), SW99.1
unnamed: D164.1 (K), SW100.1
unnamed: D165.1 (K), SW101.1
unnamed: D166.1 (K), SW102.1
unnamed: D167.1 (K), SW103.1
unnamed: D168.1 (K), SW104.1
unnamed: D169.1 (K), SW105.1
unnamed: D170.1 (K), SW106.1
unnamed: D171.1 (K), SW107.1
unnamed: D172.1 (K), SW108.1
unnamed: D173.1 (K), SW109.1
unnamed: D174.1 (K), SW110.1
unnamed: D175.1 (K), SW111.1
unnamed: D176.1 (K), SW112.1
unnamed: D177.1 (K), SW113.1
unnamed: D178.1 (K), SW114.1
unnamed: D179.1 (K), SW115.1
unnamed: D180.1 (K), SW116.1
unnamed: D181.1 (K), SW117.1
unnamed: D182.1 (K), SW118.1
unnamed: D183.1 (K), SW119.1
unnamed: D184.1 (K), SW120.1
unnamed: D185.1 (K), SW121.1
unnamed: D186.1 (K), SW122.1
unnamed: D187.1 (K), SW123.1
unnamed: D188.1 (K), SW124.1
unnamed: D189.1 (K), SW125.1
unnamed: D190.1 (K), SW126.1
unnamed: D191.1 (K), SW127.1
unnamed: D192.1 (K), SW128.1
unnamed: D193.2 (DOUT), D194.4 (DIN)
unnamed: D194.2 (DOUT), D195.4 (DIN)
unnamed: D195.2 (DOUT), D196.4 (DIN)
unnamed: D196.2 (DOUT), D197.4 (DIN)
unnamed: D197.2 (DOUT), D198.4 (DIN)
unnamed: D198.2 (DOUT), D199.4 (DIN)
unnamed: D199.2 (DOUT), D200.4 (DIN)
unnamed: D201.2 (DOUT), D202.4 (DIN)
unnamed: D202.2 (DOUT), D203.4 (DIN)
unnamed: D203.2 (DOUT), D204.4 (DIN)
unnamed: D204.2 (DOUT), D205.4 (DIN)
unnamed: D205.2 (DOUT), D206.4 (DIN)
unnamed: D206.2 (DOUT), D207.4 (DIN)
unnamed: D207.2 (DOUT), D208.4 (DIN)
unnamed: D209.2 (DOUT), D210.4 (DIN)
unnamed: D210.2 (DOUT), D211.4 (DIN)
unnamed: D211.2 (DOUT), D212.4 (DIN)
unnamed: D212.2 (DOUT), D213.4 (DIN)
unnamed: D213.2 (DOUT), D214.4 (DIN)
unnamed: D214.2 (DOUT), D215.4 (DIN)
unnamed: D215.2 (DOUT), D216.4 (DIN)
unnamed: D217.2 (DOUT), D218.4 (DIN)
unnamed: D218.2 (DOUT), D219.4 (DIN)
unnamed: D219.2 (DOUT), D220.4 (DIN)
unnamed: D220.2 (DOUT), D221.4 (DIN)
unnamed: D221.2 (DOUT), D222.4 (DIN)
unnamed: D222.2 (DOUT), D223.4 (DIN)
unnamed: D223.2 (DOUT), D224.4 (DIN)
unnamed: D225.2 (DOUT), D226.4 (DIN)
unnamed: D226.2 (DOUT), D227.4 (DIN)
unnamed: D227.2 (DOUT), D228.4 (DIN)
unnamed: D228.2 (DOUT), D229.4 (DIN)
unnamed: D229.2 (DOUT), D230.4 (DIN)
unnamed: D230.2 (DOUT), D231.4 (DIN)
unnamed: D231.2 (DOUT), D232.4 (DIN)
unnamed: D233.2 (DOUT), D234.4 (DIN)
unnamed: D234.2 (DOUT), D235.4 (DIN)
unnamed: D235.2 (DOUT), D236.4 (DIN)
unnamed: D236.2 (DOUT), D237.4 (DIN)
unnamed: D237.2 (DOUT), D238.4 (DIN)
unnamed: D238.2 (DOUT), D239.4 (DIN)
unnamed: D239.2 (DOUT), D240.4 (DIN)
unnamed: D241.2 (DOUT), D242.4 (DIN)
unnamed: D242.2 (DOUT), D243.4 (DIN)
unnamed: D243.2 (DOUT), D244.4 (DIN)
unnamed: D244.2 (DOUT), D245.4 (DIN)
unnamed: D245.2 (DOUT), D246.4 (DIN)
unnamed: D246.2 (DOUT), D247.4 (DIN)
unnamed: D247.2 (DOUT), D248.4 (DIN)
unnamed: D249.2 (DOUT), D250.4 (DIN)
unnamed: D250.2 (DOUT), D251.4 (DIN)
unnamed: D251.2 (DOUT), D252.4 (DIN)
unnamed: D252.2 (DOUT), D253.4 (DIN)
unnamed: D253.2 (DOUT), D254.4 (DIN)
unnamed: D254.2 (DOUT), D255.4 (DIN)
unnamed: D255.2 (DOUT), D256.4 (DIN)
SW_COL_8: SW65.2, SW73.2, SW81.2, SW89.2, SW97.2, SW105.2, SW113.2, SW121.2; also elsewhere on the board
SW_COL_9: SW66.2, SW74.2, SW82.2, SW90.2, SW98.2, SW106.2, SW114.2, SW122.2; also elsewhere on the board
SW_COL_10: SW67.2, SW75.2, SW83.2, SW91.2, SW99.2, SW107.2, SW115.2, SW123.2; also elsewhere on the board
SW_COL_11: SW68.2, SW76.2, SW84.2, SW92.2, SW100.2, SW108.2, SW116.2, SW124.2; also elsewhere on the board
SW_COL_12: SW69.2, SW77.2, SW85.2, SW93.2, SW101.2, SW109.2, SW117.2, SW125.2; also elsewhere on the board
SW_COL_13: SW70.2, SW78.2, SW86.2, SW94.2, SW102.2, SW110.2, SW118.2, SW126.2; also elsewhere on the board
SW_COL_14: SW71.2, SW79.2, SW87.2, SW95.2, SW103.2, SW111.2, SW119.2, SW127.2; also elsewhere on the board
SW_COL_15: SW72.2, SW80.2, SW88.2, SW96.2, SW104.2, SW112.2, SW120.2, SW128.2; also elsewhere on the board
SW_ROW_1: D129.2 (A), D130.2 (A), D131.2 (A), D132.2 (A), D133.2 (A), D134.2 (A), D135.2 (A), D136.2 (A); also elsewhere on the board
SW_ROW_2: D137.2 (A), D138.2 (A), D139.2 (A), D140.2 (A), D141.2 (A), D142.2 (A), D143.2 (A), D144.2 (A); also elsewhere on the board
SW_ROW_3: D145.2 (A), D146.2 (A), D147.2 (A), D148.2 (A), D149.2 (A), D150.2 (A), D151.2 (A), D152.2 (A); also elsewhere on the board
SW_ROW_4: D153.2 (A), D154.2 (A), D155.2 (A), D156.2 (A), D157.2 (A), D158.2 (A), D159.2 (A), D160.2 (A); also elsewhere on the board
SW_ROW_5: D161.2 (A), D162.2 (A), D163.2 (A), D164.2 (A), D165.2 (A), D166.2 (A), D167.2 (A), D168.2 (A); also elsewhere on the board
SW_ROW_6: D169.2 (A), D170.2 (A), D171.2 (A), D172.2 (A), D173.2 (A), D174.2 (A), D175.2 (A), D176.2 (A); also elsewhere on the board
SW_ROW_7: D177.2 (A), D178.2 (A), D179.2 (A), D180.2 (A), D181.2 (A), D182.2 (A), D183.2 (A), D184.2 (A); also elsewhere on the board
SW_ROW_8: D185.2 (A), D186.2 (A), D187.2 (A), D188.2 (A), D189.2 (A), D190.2 (A), D191.2 (A), D192.2 (A); also elsewhere on the board

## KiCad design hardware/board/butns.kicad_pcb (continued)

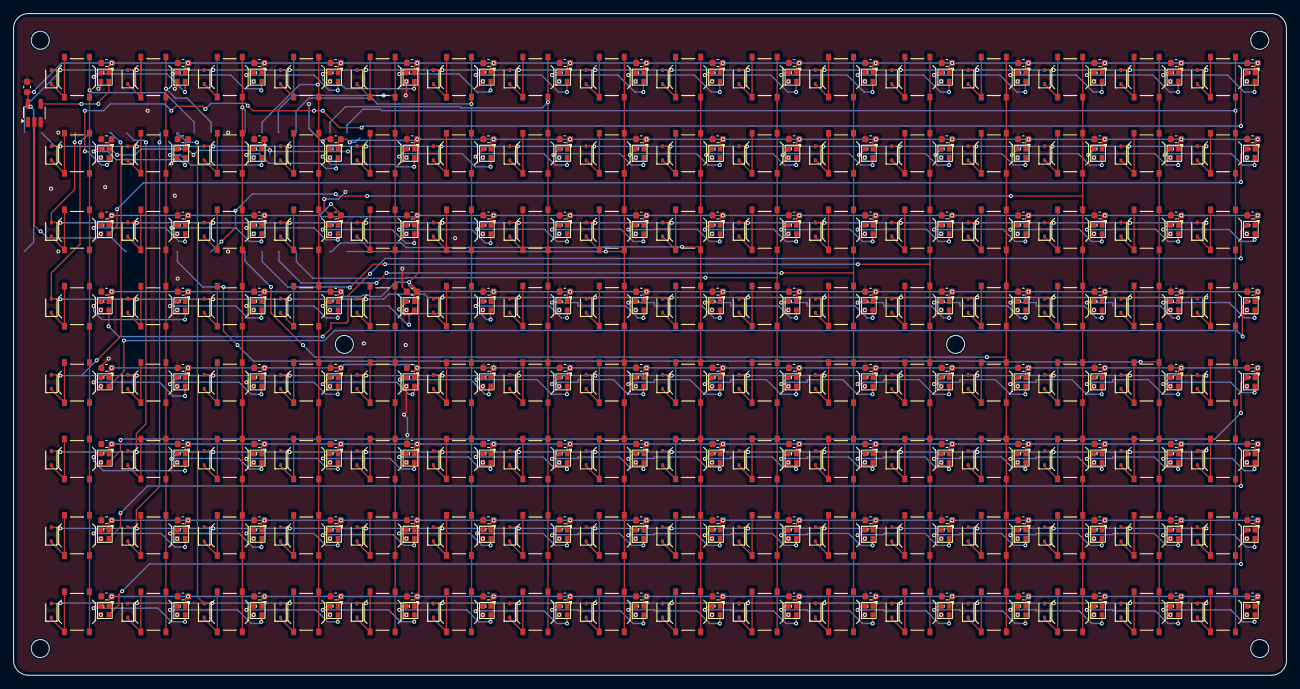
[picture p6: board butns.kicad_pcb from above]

Board: 2 copper layers, 190.4 x 99.0 mm, 521 parts (1 on the bottom side), 283 nets.

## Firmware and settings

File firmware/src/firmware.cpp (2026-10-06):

// Btns 0.6
// by Leo Kuroshita for Hügelton instruments, modified by jhbruhn.
// 16x8 variant: 8 rows x 16 columns, 128 SK6812 LEDs, no tilt sensor.

#include "MonomeSerialDevice.h"
#include <Arduino.h>
#include <Adafruit_TinyUSB.h>
#include <Adafruit_NeoPixel.h>

#define NUM_ROWS 8
#define NUM_COLS 16
#define NUM_LEDS (NUM_ROWS * NUM_COLS)
#define LED_PIN 28

// 0 = USB connector on the left (default), 2 = rotated by 180 degrees.
// Hold the top-left key (default) or the bottom-right key (180 degrees) while plugging in.
#define DEFAULT_ROTATION 0
#define DEFAULT_FLIP_HORIZONTAL false
#define DEFAULT_FLIP_VERTICAL false

// LED power budget. SK6812-EC20: 12 mA per colour channel at full scale, about 1 mA idle per LED.
// All values of a frame are scaled down together if the estimate exceeds the budget.
#define LED_MA_PER_CHANNEL 12
#define LED_MA_IDLE 1
#define MAX_LED_CURRENT_MA 400

// Matrix timing in microseconds
#define COL_SETTLE_US 5
#define COL_RELEASE_US 20

// SW_ROW_1..8 -> GPIO0..7
const uint8_t ROW_PINS[NUM_ROWS] = {0, 1, 2, 3, 4, 5, 6, 7};
// SW_COL_1..16, physical order left to right.
// Columns 1-7: GPIO8-14, columns 8-15: GPIO16-22 and GPIO26, column 16: GPIO15.
const uint8_t COL_PINS[NUM_COLS] = {8, 9, 10, 11, 12, 13, 14, 16, 17, 18, 19, 20, 21, 22, 26, 15};
const uint8_t gammaTable[16] = { 0,  2,  3,  6,  11, 18, 25, 32, 41, 59, 70, 80, 92, 103, 115, 127};
const uint8_t gammaAdj = 2;

bool isInited = false;
String deviceID = "btns";
String serialNum = "m4216124";

char mfgstr[32] = "monome";
char prodstr[32] = "monome";
char serialstr[32] = "m4216124";

Adafruit_NeoPixel pixels(NUM_LEDS, LED_PIN, NEO_GRB + NEO_KHZ800);

MonomeSerialDevice mdp;

bool buttonStates[NUM_ROWS][NUM_COLS] = {0};
uint32_t rowMask = 0;

int gridRotation = DEFAULT_ROTATION;
bool flipHorizontal = DEFAULT_FLIP_HORIZONTAL;
bool flipVertical = DEFAULT_FLIP_VERTICAL;

void updateLEDMatrix();
void scanButtonMatrix();
void mapPhysicalToGrid(int row, int col, int &y, int &x);
uint8_t readColumn(int col);
bool detectGridOrientation();

// Maps a physical position (row, col) to grid coordinates (y, x).
// Only 0 and 180 degrees keep the 16x8 shape, both mappings are their own inverse.
void mapPhysicalToGrid(int row, int col, int &y, int &x) {
    y = row;
    x = col;

    if (gridRotation == 2) {
        y = NUM_ROWS - 1 - y;
        x = NUM_COLS - 1 - x;
    }

    if (flipHorizontal) x = NUM_COLS - 1 - x;
    if (flipVertical) y = NUM_ROWS - 1 - y;
}

// Drives one column low and returns the state of all rows as a bitmask (bit = row, 1 = pressed).
uint8_t readColumn(int col) {
    digitalWrite(COL_PINS[col], LOW);
    delayMicroseconds(COL_SETTLE_US);
    uint32_t in = ~gpio_get_all() & rowMask;
    digitalWrite(COL_PINS[col], HIGH);
    // let the row pull-ups recharge the row lines before the next column is selected
    delayMicroseconds(COL_RELEASE_US);

    uint8_t result = 0;
    for (int row = 0; row < NUM_ROWS; row++) {
        if (in & (1u << ROW_PINS[row])) result |= (1 << row);
    }
    return result;
}

bool detectGridOrientation() {
    gridRotation = DEFAULT_ROTATION;
    if (readColumn(0) & 0x01) {
        gridRotation = 0;
        return true;
    }
    if (readColumn(NUM_COLS - 1) & (1 << (NUM_ROWS - 1))) {
        gridRotation = 2;
        return true;
    }
    return false;
}

void setup() {
    USBDevice.setManufacturerDescriptor(mfgstr);
    USBDevice.setProductDescriptor(prodstr);
    USBDevice.setSerialDescriptor(serialstr);

    pinMode(LED_BUILTIN, OUTPUT);

    for (int i = 0; i < NUM_ROWS; i++) {
        pinMode(ROW_PINS[i], INPUT_PULLUP);
        rowMask |= (1u << ROW_PINS[i]);
    }
    for (int i = 0; i < NUM_COLS; i++) {
        pinMode(COL_PINS[i], OUTPUT);
        digitalWrite(COL_PINS[i], HIGH);
    }
    delay(1);

    detectGridOrientation();

    mdp.isMonome = true;
    mdp.deviceID = deviceID;
    mdp.setupAsGrid(NUM_ROWS, NUM_COLS);

    isInited = true;
    mdp.poll();

    // Send grid size and rotation information
    mdp.sendSysSize();
    mdp.sendSysRotation();
    pixels.begin();
    pixels.clear();
    pixels.show();
}

void loop() {
    static unsigned long lastCheck = 0;
    unsigned long currentMillis = millis();

    mdp.poll();

    if (currentMillis - lastCheck >= 15) {
        lastCheck = currentMillis;
        scanButtonMatrix();
        updateLEDMatrix();
    }
}

void scanButtonMatrix() {
    for (int col = 0; col < NUM_COLS; col++) {
        uint8_t pressed = readColumn(col);
        for (int row = 0; row < NUM_ROWS; row++) {
            bool currentState = pressed & (1 << row);
            if (currentState != buttonStates[row][col]) {
                int x, y;
                mapPhysicalToGrid(row, col, y, x);
                mdp.sendGridKey(x, y, currentState);
                buttonStates[row][col] = currentState;
            }
        }
    }
}

void updateLEDMatrix() {
    static uint8_t level[NUM_LEDS];
    uint32_t sum = 0;

    // LED chain runs row by row, 16 LEDs per row, starting at the top left
    for (int row = 0; row < NUM_ROWS; row++) {
        for (int col = 0; col < NUM_COLS; col++) {
            int x, y;
            mapPhysicalToGrid(row, col, y, x);
            uint8_t intensity = gammaTable[mdp.leds[y * NUM_COLS + x] & 0x0F] * gammaAdj;
            level[row * NUM_COLS + col] = intensity;
            // colour is (i/2, i, i/2)
            sum += intensity + 2 * (intensity / 2);
        }
    }

    // estimated current in mA
    uint32_t budget = MAX_LED_CURRENT_MA - NUM_LEDS * LED_MA_IDLE;
    uint32_t estimate = sum * LED_MA_PER_CHANNEL / 255;
    uint32_t scale = 256;
    if (estimate > budget) scale = budget * 256 / estimate;

    for (int i = 0; i < NUM_LEDS; i++) {
        uint8_t intensity = (level[i] * scale) >> 8;
        pixels.setPixelColor(i, pixels.Color(intensity / 2, intensity, intensity / 2));
    }
    pixels.show();
}

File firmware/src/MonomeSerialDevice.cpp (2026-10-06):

#include "MonomeSerialDevice.h"
#include "debug.h"

MonomeSerialDevice::MonomeSerialDevice() {}

void MonomeSerialDevice::initialize() {
  active = false;
  isMonome = false;
  isGrid = true;
  rows = 0;
  columns = 0;
  encoders = 0;
  //clearQueue();
  clearAllLeds();
  arcDirty = false;
  gridDirty = false;
}

void MonomeSerialDevice::setupAsGrid(uint8_t _rows, uint8_t _columns) {
  initialize();
  active = true;
  isMonome = true;
  isGrid = true;
  rows = _rows;
  columns = _columns;
  gridDirty = true;
  debugfln(INFO, "GRID rows: %d columns %d", rows, columns);
}

void MonomeSerialDevice::setupAsArc(uint8_t _encoders) {
  initialize();
  active = true;
  isMonome = true;
  isGrid = false;
  encoders = _encoders;
  arcDirty = true;
  debugfln(INFO, "ARC encoders: %d", encoders);
}

void MonomeSerialDevice::setTiltActive(uint8_t sensor, bool active) {
  if (sensor < 4) {
    tiltActive[sensor] = active;
  }
}

void MonomeSerialDevice::sendTiltEvent(uint8_t sensor, int8_t xh,int8_t xl,int8_t yh,int8_t yl,int8_t zh,int8_t zl) {
    if (sensor < 4 && tiltActive[sensor]) {

        Serial.write((uint8_t)0x81);  // tiltイベントのプレフィックス
        Serial.write(sensor);
        Serial.write((int8_t)xh);
        Serial.write((int8_t)xl);
        Serial.write((int8_t)yh);
        Serial.write((int8_t)yl);
        Serial.write((int8_t)zh);
        Serial.write((int8_t)zl);
    }
}


void MonomeSerialDevice::getDeviceInfo() {
  //debugln(INFO, "MonomeSerialDevice::getDeviceInfo");
  Serial.write(uint8_t(0));
}

void MonomeSerialDevice::poll() {
  //while (isMonome && Serial.available()) { processSerial(); };
  if (Serial.available()) {
    processSerial();
  }
  //Serial.println("processSerial");
}


void MonomeSerialDevice::setAllLEDs(int value) {
  for (int i = 0; i < MAXLEDCOUNT; i++) leds[i] = value;
}

void MonomeSerialDevice::setGridLed(uint8_t x, uint8_t y, uint8_t level) {
  //    int index = x + (y * columns);
  //    if (index < MAXLEDCOUNT) leds[index] = level;

  if (x < columns && y < rows) {
    uint32_t index = y * columns + x;
    leds[index] = level;
  }
  //debugfln(INFO, "LED index: %d x %d y %d", index, x, y);
}

void MonomeSerialDevice::clearGridLed(uint8_t x, uint8_t y) {
  setGridLed(x, y, 0);
  //Serial.println("clearGridLed");
}

void MonomeSerialDevice::setArcLed(uint8_t enc, uint8_t led, uint8_t level) {
  int index = led + (enc << 6);
  if (index < MAXLEDCOUNT) leds[index] = level;
  //Serial.println("setArcLed");
}

void MonomeSerialDevice::clearArcLed(uint8_t enc, uint8_t led) {
  setArcLed(enc, led, 0);
  //Serial.println("clearArcLed");
}

void MonomeSerialDevice::clearAllLeds() {
  for (int i = 0; i < MAXLEDCOUNT; i++) leds[i] = 0;
  //Serial.println("clearAllLeds");
}

void MonomeSerialDevice::clearArcRing(uint8_t ring) {
  for (int i = ring << 6, upper = i + 64; i < upper; i++) leds[i] = 0;
  //Serial.println("clearArcRing");
}

void MonomeSerialDevice::refreshGrid() {
  gridDirty = true;
  //Serial.println("refreshGrid");
}

void MonomeSerialDevice::refreshArc() {
  arcDirty = true;
  //Serial.println("refreshArc");
}

void MonomeSerialDevice::sendSysSize() {
  Serial.write((uint8_t)0x05);  // system / get grid size
  Serial.write((uint8_t)columns);
  Serial.write((uint8_t)rows);
}

void MonomeSerialDevice::sendSysRotation() {
  // Note: The original Monome protocol doesn't have a direct command for rotation.
  // This is a custom implementation. You may need to adjust how the host interprets this.
  Serial.write((uint8_t)0x0F);  // Using 0x0F (system / report firmware version) as a custom command
  Serial.write((uint8_t)0xF0);  // Custom identifier for rotation
  Serial.write((uint8_t)gridRotation);
}

void MonomeSerialDevice::refresh() {
  /*
    uint8_t buf[35];
    int ind, led;

    if (gridDirty) {
        //Serial.println("gridDirty");
        buf[0] = 0x1A;
        buf[1] = 0;
        buf[2] = 0;

        ind = 3;
        for (int y = 0; y < 8; y++)
            for (int x = 0; x < 8; x += 2) {
                led = (y << 4) + x;
                buf[ind++] = (leds[led] << 4) | leds[led + 1];
            }
        Serial.write(buf, 35);
        
        ind = 3;
        buf[1] = 8;
        for (int y = 0; y < 8; y++)
            for (int x = 8; x < 16; x += 2) {
                led = (y << 4) + x;
                buf[ind++] = (leds[led] << 4) | leds[led + 1];
            }
        Serial.write(buf, 35);
        
        ind = 3;
        buf[1] = 0;
        buf[2] = 8;
        for (int y = 8; y < 16; y++)
            for (int x = 0; x < 8; x += 2) {
                led = (y << 4) + x;
                buf[ind++] = (leds[led] << 4) | leds[led + 1];
            }
        Serial.write(buf, 35);

        ind = 3;
        buf[1] = 8;
        for (int y = 8; y < 16; y++)
            for (int x = 8; x < 16; x += 2) {
                led = (y << 4) + x;
                buf[ind++] = (leds[led] << 4) | leds[led + 1];
            }
        Serial.write(buf, 35);
        
        gridDirty = false;
    }

    if (arcDirty) {
        //Serial.print("arcDirty");
        buf[0] = 0x92;

        buf[1] = 0;
        ind = 2;
        for (led = 0; led < 64; led += 2)
            buf[ind++] = (leds[led] << 4) | leds[led + 1];
        Serial.write(buf, 34);
        
        buf[1] = 1;
        ind = 2;
        for (led = 64; led < 128; led += 2)
            buf[ind++] = (leds[led] << 4) | leds[led + 1];
        Serial.write(buf, 34);

        buf[1] = 2;
        ind = 2;
        for (led = 128; led < 192; led += 2)
            buf[ind++] = (leds[led] << 4) | leds[led + 1];
        Serial.write(buf, 34);
        
        buf[1] = 3;
        ind = 2;
        for (led = 192; led < 256; led += 2)
            buf[ind++] = (leds[led] << 4) | leds[led + 1];
        Serial.write(buf, 34);
        
        buf[1] = 4;
        ind = 2;
        for (led = 256; led < 320; led += 2)
            buf[ind++] = (leds[led] << 4) | leds[led + 1];
        Serial.write(buf, 34);

        buf[1] = 5;
        ind = 2;
        for (led = 320; led < 384; led += 2)
            buf[ind++] = (leds[led] << 4) | leds[led + 1];
        Serial.write(buf, 34);

        buf[1] = 6;
        ind = 2;
        for (led = 384; led < 448; led += 2)
            buf[ind++] = (leds[led] << 4) | leds[led + 1];
        Serial.write(buf, 34);

        buf[1] = 7;
        ind = 2;
        for (led = 448; led < 512; led += 2)
            buf[ind++] = (leds[led] << 4) | leds[led + 1];
        Serial.write(buf, 34);

        arcDirty = 0;
    }
*/
}
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

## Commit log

2026-10-06 Convert to 16x8 grid (8 rows x 16 columns)
    Hardware
    - PCB extended to 190.44 x 99 mm with eight additional columns:
    128 switches, 128 diodes, 128 SK6812-EC20, 129 capacitors
    - New column nets SW_COL_8..15 on GPIO16-22 and GPIO26, former
    SW_COL_8 (GPIO15) is now SW_COL_16
    - LED chain runs row by row over 16 columns
    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
    [BOM-butns.csv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]
2026-10-09 Add adjustable maximum LED brightness via key combination
    Hold both top corner keys for 1 s to enter the setting, press a key in
    column 1..16 to select 1/16..16/16 of full brightness. The mode ends 3 s
    after the last key press, the value is stored in flash (EEPROM emulation).
    Claude-Session: https://claude.ai/code/session_0195H63MEXeeVZ7CNyHAeb6N
2026-10-27 Add iii firmware with colour support (firmware-iii)
    pico-sdk firmware for the 16x8 board with two modes, stored in flash:
    - iii: monome iii Lua scripting (diii, USB MIDI, file system), USB id
    CAFE:1101 as expected by diii. Grid API plus colour extensions
    grid_color, grid_led_rgb, grid_color_intensity as in the NeoTrellis
    iii firmware and the diii NeoTrellis emulator.
    - monome: serial protocol for serialosc / norns.
    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
2026-11-03 Case: lower base from 20 mm to 10 mm
    standoffHeight 15 -> 5, baseWallHeight 18 -> 8. The space between PCB
    and lid is unchanged. Below the PCB 5 mm remain for the Pico (about
    3.1 mm incl. USB connector, from its 3D model). The USB cutout follows
    the PCB and stays above the base floor.
    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
2026-11-03 Case: light blockers in the lid, slots in the TPU inlay
    Walls hang from the lid between neighbouring key columns, in front of
    each LED (8 rows x 15 gaps). They end 0.4 mm above the PCB, and 1.5 mm
    above the PCB over the diode of the next key. Thin part (0.6 mm) beside
    the cap tabs of the button mat, thicker ends outside of them, length
    limited so the diagonal ribs of the mat pass. The right face is flush
    with the lid hole, so the caps keep their play.
    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
2026-11-03 Case: light blockers v2, also between the key rows
    Additional walls in the gaps between the key rows, above and below every
    LED (7 gaps x 16 columns). Deep part beside the LED down to 0.4 mm above
    the PCB, shallow part over the diagonal ribs of the button mat ending
    2.0 mm above the PCB. 0.1 mm clearance to both lid holes. The inner
    screws H5/H6 stay free. Switch off with lightBlockersRowGaps = false.
    Mesh check of lid and button mat in 27 positions (+-0.25 mm sideways,
    pressed 0.3 mm, lifted 0.2 mm): no contact.
    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
2026-11-04 firmware-iii: fix freeze with large scripts (stepiii)
    The Lua heap outgrew the RAM: iii's default GC (pause 250) lets the heap
    grow to 2.5 times the live data, stepiii keeps about 130 KB live, and the
    failed realloc() halted the firmware through the pico-sdk malloc panic.
    - own Lua allocator and GC settings via --wrap=lua_newstate: incremental
    GC with pause 100, Lua limited to the heap minus 40 KB, emergency GC and
    a Lua error instead of a halt at the limit (PICO_MALLOC_PANIC=0)
    - upload next to a large running script: stop the script if compiling
    the upload runs out of memory (--wrap=vm_test_script)
    - bounded serial(): iii's version wrote past its 16 KB buffer when errors
    kept comi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
2026-11-05 Case: pin hole in the base for the Pico BOOTSEL button
    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
